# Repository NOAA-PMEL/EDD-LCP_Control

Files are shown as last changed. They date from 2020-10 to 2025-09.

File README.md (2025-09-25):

# Legal Disclaimers

## Software Disclaimer
*This repository is a software product and is not official communication 
of the National Oceanic and Atmospheric Administration (NOAA), or the 
United States Department of Commerce (DOC).  All NOAA GitHub project 
code is provided on an 'as is' basis and the user assumes responsibility 
for its use.  Any claims against the DOC or DOC bureaus stemming from 
the use of this GitHub project will be governed by all applicable Federal 
law.  Any reference to specific commercial products, processes, or services 
by service mark, trademark, manufacturer, or otherwise, does not constitute 
or imply their endorsement, recommendation, or favoring by the DOC. 
The DOC seal and logo, or the seal and logo of a DOC bureau, shall not 
be used in any manner to imply endorsement of any commercial product 
or activity by the DOC or the United States Government.*

## Hardware Disclaimer
*NOAA does not intend to patent this work worldwide. It may be used freely, but NOAA does not warrant its fitness for any use.*

*As a work of the United States Government, the associated schematics and software are in the public domain within the United States. Additionally, NOAA waives any potential copyright and related rights in the associated schematics and software worldwide through the Creative Commons Zero (CC0) 1.0 Universal Public Domain Declaration.*
# EDD-LCP_Control
Control PCB &amp; Firmware for Low Cost Profiler.

This repository is home to the system controller PCB design and firmware for the low-cost profiler project.

## State of this project
The LCP has been extensilivly tested and deployed in Puget Sound and the Bering Sea in Moored mode.  The mechanical design is complete, the electronics hardware needs a goround-up re-design for lower power consumption, decreased cost, and robustness.  The Firmware needs a ground up re-write for robustnuss and readability.

# Branch
Ver1.0 is the active branch and encompasses the most upto date version of the project 

# Low-Cost-Profiler
Low Cost Profiler for Oceanographic Monitoring

## Profiler System Diagram
```mermaid
graph LR;

    subgraph Low Cost Profiler

    MainController --- PistonController
    GPS --> MainController
    Pressure --> MainController
    Temperature --> MainController
    IMU --> MainController
    Accelerometer --> MainController
    subgraph Profiler Control
        MainController
        subgraph sensors
            Pressure
            Temperature
            GPS 
            IMU
            Accelerometer
        end

        IridiumSBD --- MainController
        subgraph Telemetry
        IridiumSBD
        end
    end

    subgraph Power Control ;
    Piston --> PistonController
    Encoder --> PistonController
    subgraph motion
    Encoder
    Piston
    end
    Batteries --> PistonController
    subgraph power
    Batteries
    end
    BatteryFuelGauge --> PistonController
    subgraph Sensor2
    BatteryFuelGauge     
    end
    end
    
    end
```

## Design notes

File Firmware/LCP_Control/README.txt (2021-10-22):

Name:
=====
 freertos_lowpower

Description:
============
 Example of the app running under FreeRTOS.

This example implements LED task within the FreeRTOS framework. It monitors
three On-board buttons, and toggles respective on-board LEDs in response.
To save power, this application is compiled without print
statements by default. To enable them, add the following project-level
macro definitions.

AM_DEBUG_PRINTF

If enabled, debug messages will be sent over ITM.

******************************************************************************

State of the world (project):

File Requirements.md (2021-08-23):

# LCP Control Requirements

## Introduction
This document captures the electrical and firmware requirements of the Low-Cost Profiler.

## Electrical Requirments

## Firmware Requirements
### Sensors
- [ ] Pressure sensor
- [ ] Temperature sensor
- [ ] GPS
- [ ] Accelerometer
  - [ ] Double tap recognition
  - [ ] Tilt 
  - [ ] Oscillation

### COMs
- [ ] UART 
- [ ] I2C
- [ ] SPI
- [ ] Iridium 
- [ ] Bluetooth

### Analog
- [ ] Bus voltage monitoring

### Low Power Mode
- [ ] Low Power Mode

### Application Level
  - [ ] Console
    - [ ] Set
      - [ ] See Config Parameters
    - [ ] Get 
      - [ ] See Config Parameters
    - [ ] Stream data
      - [ ] Debug
      - [ ] Warnings
      - [ ] Errors
      - [ ] All
  - [ ] Config
    - [ ] Bluetooth Config
    - [ ] Other?
  - [ ] Control Mode
    - [ ] Dive Mode
    - [ ] Park Mode
    - [ ] Dive 2 Mode
    - [ ] Profile Mode
    - [ ] Surface Mode
    - [ ] Transmit Mode
  - [ ] Deployment Mode
    - [ ] Storage Mode
    - [ ] Config Mode
    - [ ] Deploy Mode
    - [ ] Seek Mode
    - [ ] Profile Mode
    - [ ] Moored Mode
    - [ ] Pop-up Mode
  - [ ] Motion Control
    - [ ] State/Estimation
    - [ ] Current state
    - [ ] Piston Control
  - [ ] Data Acquisition
    - [ ] Depth Estimation
    - [ ] Chemistry
      - [ ] Temperature
      - [ ] CTD [Future] 
      - [ ] Chlor-A [Future]
      - [ ] PAR [Future]
    - [ ] Position/Tilt
      - [ ] GPS
      - [ ] Accleration
      - [ ] IMU
  - [ ] RTOS
    - [ ] Modes
    - [ ] Threads
    - [ ] Scheduling
    - [ ] Queues

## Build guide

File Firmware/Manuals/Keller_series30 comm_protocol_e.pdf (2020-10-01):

KELLER AG für Druckmesstechnik | Version 3.5 BV/SM 27. January 2017

# Description of the Communication protocol

for Series 30 and Series40 pressure transmitters from KELLER Class.Group = 5.20
Class.Group = 5.21

Version 3.5

Communication protocol Serie30 | Page 2/36

### 1 Introduction

This document describes the communications protocol for the Series 30 digital pressure transmitters from KELLER Druckmesstechnik. In addition to these transmitters, other devices such as data loggers or manometers are also offered. These products are distinguished by the designation CLASS. Within this device class, the individual device groups are differentiated by the designation GROUP. All Series 30 pressure transmitters bear the CLASS designation 5.

The software version number consists of following components:

short-designator: | Class | Group | Year | Week
| Device group | | SW-Version
Series 30 and 40 | 5 | 20 | SW-Version: release year | SW-Version: release week
Series 30 X2 | 5 | 21 | SW-Version: release year | SW-Version: release week

In this document, the software version is defined by Class.Group-Year.Week, e.g. 5.20-5.50.

The protocol itself is based on MODBUS, but incorporates optimised functions for the device, these functions are called Keller bus functions. However, minimum (only fct3) MODBUS RTU functionality is implemented for devices CLASS.GROUP = 5.20 with firmware 2.40 and newer. Full MODBUS support is provided from firmware 5.20-10.XX on and in 5.21-XX.XX.

See Appendix for an overview of the different versions.

### 2 Bit transfer layer (physical layer)

### 2.1 Introduction

The physical connection is provided by the RS485 serial interface. This guarantees good interference immunity and enables a flexible bus structure, i.e. several devices can be administrated as slaves by a single master. In order to minimise the scope of cabling, the RS485 is used in half-duplex mode. This means that 2 wires are required for communications and 2 wires for power in feed.

### 2.2 Characteristic

In order to operate several devices at one serial interface, they are simply all connected in parallel (RS485A, RS485B, GND and +Vcc). Before incorporating the devices into the bus, each device must be programmed with a different address.

It is possible to configure a network up to a length of 1300 metres with a maximum of 128 devices. Each riser cable may be up to 14 m in length. The employed cable should correspond to specification EIA RS485.

master

max. 1300m

max. 14m

dev. 1 | dev. 2 | dev. n

### 2.3 RS485 half-duplex details

To ensure best possible operation in an industrial environment Keller uses RS485 driver with tailored characteristics. To provide compatibility and get full advantage the bus driver of the master device has to support these specifications.

slew rate limited | In order to avoid oscillations and interference the signal slew rate is limited. This measure allows also usage of standard cables or non-standard topologies (e.g. level detectors or branch lines >> 14m). The more, termination is less critical and has not to be implemented compulsory at the line ends, a feature important for level detectors.
fail safe | Defined signal level – even in short or open circuit case. This is very important for half-duplex operation if all devices are in reception mode – here the line is open in case that no bias resistors are implemented at the master.
1/8 unit load | Input impedance is lower than defined by the RS485 standard, this allows connecting up to 128 devices to the bus.

Termination
Layout: between A and B at the beginning and the end of the transmission line

Value: the same as the line-impedance. Type.: 120Ohm.

In case of a fail-safe master driver (interface converter to the PC) and a noise-free environment the termination resistor are not mandatory. To reduce current peaks the resistor value can be chosen higher (1kOhm) or omitted (while transmitting the current needed for 2x120Ohm is about 50mA).

To ensure a stable communication at least one terminal resistor is necessary (mostly included in the master-RS485 driver)! One can do without a terminal resistor, if the environment is free of interference and the cable is held short (a few meters).

If the transmitter has additionally an analogue 4...20mA (two wire) output which will be used simultaneously with the serial communication, it could be useful to communicate without terminal resistor. Otherwise the analogue current signal will have heavy interferences. See application note: App. Note S30X-011 RS485 and current loop.pdf

The transmitters will never have a terminal resistor built in internally.

Bias-resistors
To keep up having always defined voltages one can switch pull-up respectively pull-down resistors to the transmitter:
From A to +5V and from B to GND. This is necessary when such RS485 drivers are in use which are not fail-save. This is not necessary for our products when the master is fail-safe.

Common Mode
The common-mode of the data circuit line is +12 / -7V down to GND. It is essential to keep up with this. Always connect the GND of the RS485 converter of the master with GND of the transmitter!

Definition of data circuit line assignments
signal | Designation of Keller and divers manufacturers… | Designation of the EIA Standard
inverted (-) | B | A
non-inverted (+) | A | B

Further information on RS485: http://www.maxim-ic.com/MaximProducts/Interface/rs-485.htm

### 3 Data-link layer

This section describes how data interchange is affected on this bus. The data and their check and control structures are grouped together to form messages. These constitute the smallest communication unit, i.e. only messages can be exchanged between the devices. As a half-duplex protocol is in use here, only one device can use the bus as a transmitter at any one time. All other devices are then in receive mode. The master takes the form of a PC or microcontroller, for example, and the devices are the slaves. Each message exchange takes place under the control of the master. The message contains the address for the receiving slave.

This results in the following 2 options for data interchange:

a) Broadcasting | This mode of communication enables the master to transmit a message to all slaves simultaneously. The master does not receive a reply, however, and is thus unable to check whether the message has been correctly received by every slave.
b) Data interchange | This mode of communication enables the master to communicate with a single slave. This normally involves the transmission of two messages: the master transmits a request and the slave responds to this request. Only the master is permitted to request a response. The request is received by every slave, but only the selected slave responds. The response must be received within a stipulated time, otherwise the master will assess the attempt as failed and must transmit the request again.

### 3.1 Transmission format for the serial interface

The data are transmitted serially via the bus. The following format applies:
- 1 start bit
- 8 data bits (the least significant bit first)
- 1 stop bit
- no parity (default)
- 9600 baud (default) or 115’200 Baud

This results in 10 bits (11 bits with active parity bit) per transmission byte.

### 3.2 Format of a message

### 3.2.1 Format of the message sent by the master

Note on the presentation of messages: Each box presents 1 data byte consisting of 8 bits, unless otherwise stated.

Each message sent by the master possesses the following format:

DevAddr | 0 | Function code
n byte parameters
(optional)

KELLER:CRC16_H
MODBUS:CRC16_L

KELLER:CRC16_L
MODBUS:CRC16_H
- DevAddr: Address of the device.
Address 0 is reserved for broadcasting.
Addresses 1 (default) ...249 can be used for bus mode.
Address 250 is transparent and reserved for non-bus mode. Every device can be contacted with this address. Addresses 251...255 are reserved for subsequent developments.
- Function code: Function number
A function is selected and executed by the device via the function number. The function number is encoded in 7 bits. Bit 7 is always 0. The functions are described further below.
- Parameters: The parameters required by the function (n = 0 .. 6, according to function)

- CRC16: 16-bit checksum
These two check bytes serve to verify the integrity of the received data. If an error is established, the entire message will be discarded. The principle employed for CRC16 calculation is described in the appendix. The CRC16 standard is applied here.

Note: The length of a message from the master is at least 4 bytes.

### 3.2.2 Format of the message sent by the slave

A message transmitted by the slave possesses the following format:

DevAddr | X | Function
| | code

n byte data
(optional)

KELLER:CRC16_H
MODBUS:CRC16_L

KELLER:CRC16_L
MODBUS:CRC16_H
- DevAddr: Address of the device. This address corresponds to the address of the responding device.
- Function code:
The function number is identical to the function number sent by the master. If the most significant bit is X = 0, this indicates that the function has been executed correctly. If bit X = 1, an exception error has occurred.
- Data: Any data requested via the function follow here.
- CRC16: See above.

Note: A message from the slave has a minimum length of 5 bytes, and a maximum length of 10 bytes (Class.Group-version = 5.20-XX.XX) or 100 bytes (Class.Group-version = 5.21-XX.XX).

### 3.3 Principle of message interchange

### 3.3.1 General rules

- An address may only be allocated to one device connected to the bus. If two devices on the bus have the same address, both will respond, leading to a conflict.
- Every data interchange is initiated by the master. This means that a device may only transmit data if requested to do so by the master.
- A message consists of several bytes. These bytes are transmitted without any interruption.
Maximal time between two bytes:
1.5ms @ 9600 baud (1.5 byte length)
0.20 ms @ 115200 baud (2.3 byte length)
If the time between two bytes exceed the specified time, the slave ignores the received data, because of wrong message length or CRC value. In that case the answer is omitted.
- The addressed device must respond within time T1, otherwise the message will be invalid.

Bit frame:

ST | D0 | D1 | D2 | D3 | D4 | D5 | D6 | D7 | SP | ST | D0 | … | D6 | D7 | SP
ST: start bit, | SP: stop bit. A parity bit (if active) is inserted before the SP, D0 .. D7: 8 data bits

Message frame:

Response times:
- T1: Time between receipt of inquiry and beginning of response.
min 1.2 ms @ 9600 baud to max. 100ms for all functions and devices.
min 1 ms @ 115200 baud to max. 100ms for all functions and devices.
firmware 5.20: | Most functions (except those with EEPROM access like information values):T1 min. 1.2… 3ms
firmware 5.21: | T1 : 1.3ms – 1.8ms for F30, F32, F48, F69,F73 and F74
T1 : 7.3ms – 7.6ms for F31, F33, F66 and F95
With Modbus communication the duration of T1 depends on the number of register to read or write, while write takes much more time than read. (Write: typ. 7.2ms per register)
- T2: Time to ready-to-receive state for the slave: min 0.5 ms @ 9600 baud
min 0.5 ms @ 115200 baud

### 3.3.2 Treatment of errors

2 types of errors may occur during the interchange of messages between master and slave: transmission errors and exception errors.

### 3.3.2.1 Transmission errors

These errors are primarily accountable to line faults. The message format is incorrect. The following problems are possible:
- A received message is too short. → e.g. too much of time gap in frame between the bytes.
- A message is longer than the internal transmission buffer permits.
- The word length cannot be interpreted correctly.
- The CRC16 checksum is incorrect.
In these cases the slave denies the request and will therefore not reply. This will lead to a timeout at the master. → the request has to be repeated again.
In response to a transmission error, all received data are ignored. The slave remains in receive mode while the master is required to initiate a new data interchange.

### 3.3.2.2 Exception errors

The message has been received correctly (no transmission error has occurred), but the transmitted function number and/or the parameters are invalid. The slave responds with an exception error, unless the message has been received in broadcasting mode.
The message transmitted as a response by the slave has the following format:
DevAddr | 1 | Function
code

Exception
code

KELLER:CRC16_H
MODBUS:CRC16_L

KELLER:CRC16_L
MODBUS:CRC16_H

5 types of exception errors are defined:
- | illegal non-implemented function | 1
- | illegal data address | 2
- | illegal data value | 3
- | Slave device failure | 4
- | initialisation (only KELLER bus) | 32

Exception error 32 occurs when the device is started up anew and initialisation has not been carried out. This happens every time the device is connected anew after a break in the power supply.

Master:
Request

Master:
Request

Slave:
Response
T1 | T2

### 4 MODBUS communication

### 4.1 MODBUS Communication Basics

Mode: | RTU Mode (ASCII is not supported)
Coding System: | 8–bit binary, hexadecimal 0–9, A–F
| Two hexadecimal characters (bytes) contained in each 8–bit field of the message
Bits per Byte: | 1 start bit
| 8 data bits, least significant bit sent first
| No parity (default) 1 parity bit: even or odd parity (programmable)
| 1 stop bit (default) 2 stop bit (programmable) only firmware 5.21-XX.XX
Error Check Field: | 2 Byte Cyclical Redundancy Check (CRC)
Baudrate: | programmable 9’600 (default) or 115’200

Frame Layout:
> 3.5 char (byte) start delimiter | 8 bit addr 8 bit fkt code n x 8bit data (max n = 252)

16 bit
CRC
LOW / HIGH

> 3.5 char (byte)
end delimiter

The entire message frame must be transmitted as a continuous stream of characters. If a silent interval of more than 1.5 character times occurs between two characters, the message frame is declared incomplete and should be discarded by the receiver.

Bus Addressing:
Unicast addresses: each slave has an address between 1 (default) and 247.
Broadcast addresses: address 0 is used for broadcast frames, the slave accepts the command but must not generate an answer. Special addresses: addresses 248 – 255 are reserved. The address 250 is used for non-bus (point-to-point) communication to address a slave with unspecified or unknown address (not MODBUS standard).

Function Code:
The 8-bit value function code describes the operation that is performed on the slave. Implemented MODBUS functions are described in the following chapter.

### 4.2 Using MODBUS with KELLER products

Both protocols are active. For MODBUS only a subset of the MODBUS functionality is implemented and the implemented MODBUS function codes are not used in the KELLER-protocol. Please note, that the responses are different for both protocols.

Furthermore note that for MODBUS communication NO initialization is required to be performed before any other command.

Attention: The Error Check Field byte alignment differs.
| Modbus | KELLER-Protocol
CRC-16 | L:H | H:L

### 4.3 Description of MODBUS functions

This section describes the MODBUS functions supported by Series 30 transmitters (device Class.Group = 5.20-XX.XX and 5.21-XX.XX)

Overview:
F3: | Read registers on MODBUS address space
F6: | Write single register on MODBUS address space
F8: | MODBUS Echo function
F16: | Write multiple registers on MODBUS address space

Versions overview
The main difference between firmware 5.20 and 5.21 is, that the buffer size in version 5.21 is larger (100 byte).
The table below gives you an overview which Firmware-version supports which MODBUS functions:
Version | F3 float values 0x0000..0x000A | F3 float values 0x0100..0x0106 | F3 int 16bit values 0x0010.. 0x0015 | F3 int 32bit values 0x0020.. 0x002A | F3 Information& Configuration | F6 | F8, F16 | Data buffer size
5.20-5.50 | Yes | No | Yes | No | No | No | No | 10 byte
5.20-10.40 | Yes | Yes | No | No | Yes | No | Yes | 13 byte
5.20-12.28 | Yes | Yes | Yes | Yes | Yes | Yes | Yes | 13 byte
5.21-13.10 (and later) | Yes | Yes | Yes | Yes | Yes | Yes | Yes | 100 byte

Note: compatible for all versions to read process values (CH0..TOB2): F3 float, reg 0x0000..0x000A

### 4.4 Modbus Communication Examples

Read | address | request | response | received value
P1 | 1 | 1 3 0 2 0 2 101 203 | 1 3 4 63 117 240 123 227 222 | 0.960701 bar
P2 | 1 | 1 3 0 4 0 2 133 202 | 1 3 4 63 118 6 224 21 213 | 0.961042 bar
TOB1 | 1 | 1 3 0 8 0 2 69 201 | 1 3 4 65 181 192 121 110 11 | 22.719 °C
P1, TOB1 | 1 | 1 3 1 0 0 4 69 245 | 1 3 8 63 117 227 210 65 182 28 32 160 119 | 0.960508 bar 22.7637 °C

### 4.5 Function 3: MODBUS Register Read

Read a number of subsequent registers in the MODBUS address space starting with StAdd. Note, that the data returned has to be interpreted according the definitions in “4.9 MODBUS Register Map”.
- Function is implemented in devices Class.Group-version = 5.20-2.40 and later and 5.21-XX.XX.
- The maximal number of registers read in one cycle is limited to:
up to 4 registers for versions Class.Group-version = 5.20-10.40 and later
up to 80 registers for versions Class.Group-version = 5.21-XX.XX
up to 2 registers for earlier versions than Class.Group-version = 5.20-10.40
- Byte-count of the answer will be an even number (1 register = 2 bytes)
- Double sized process values (CH0, P1, P2, T, TOB1 and TOB2) must be read in one request.
- Returns NaN (float) or ovl (integer) in case of a inactive channel or a error in the channel

Request:
DevAddr | 0x03 | StAdd H | StAdd L | # Reg H | # Reg L | CRC16_L | CRC16_H
Response:
DevAddr | 0x03 | # Bytes | Data H | Data L | … | Data L | CRC16_L | CRC16_H
Error:
DevAddr | 0x83 | Error | CRC16_L | CRC16_H
Error codes:

### 2 Illegal data address:

- Wrong starting-address or wrong number of registers
- Start-address not defined, register exceeding defined range return 0x0000

### 3 Illegal data value:

- Quantity of requested registers out of bound

- Must be <= 4 for devices Class.Group-version = 5.20-10.XX and later
- Must be <= 80 for devices Class.Group-version = 5.21-XX.XX
- Must be <= 2 for devices Class.Group-version = 5.20-2.50

### 4.6 Function 6: MODBUS Single Register Write

This function has the same functionality as F16, but writes only 1 register.
- Function is implemented in devices Class.Group-version = 5.20-12.XX and later and 5.21-XX.XX
- A register contains 2 bytes (16 bit).
- Use this function for single configuration steps, because the returned error is easily distinguishable from other register writes.
- Note that single register operations are not allowed in the address ranges 0x03XX and 0xFFXX.

Request:

DevAddr | 0x06 | StAdd H | StAdd L | Data H | Data L | CRC16_L | CRC16_H

Response:

DevAddr | 0x06 | StAdd H | StAdd L | Data H | Data L | CRC16_L | CRC16_H

Error:

DevAddr | 0x86 | Error | CRC16_L | CRC16_H

Error codes:

### 2 Illegal data address

- address not accessible by function 6
- Start-address not defined (for writing)

### 3 Illegal data value

- frame length incorrect

### 4 Slave Device Failure

- Attempted to write into a protected register
- The data written is outside the defined data range

### 4.7 Function 8: MODBUS Echo Test

This function may be used to perform a quick line check. It just returns the data received.
- Function is implemented in devices Class.Group-version = 5.20-10.XX and later and 5.21-XX.XX
- Data may be any 2 byte value

Request:

DevAddr | 0x08 | 0x00 | 0x00 | Data H | Data L | CRC16_L | CRC16_H

Response:

DevAddr | 0x08 | 0x00 | 0x00 | Data H | Data L | CRC16_L | CRC16_H

Error:

DevAddr | 0x88 | Error | CRC16_L | CRC16_H

Error codes:

### 1 Illegal subfunction code:

- The subfunction code is not supported (it is not (0x00, 0x00)). Class.Group-version = 5.21-XX.XX only

### 3 Illegal data value:

- The data following the function code was not the fixed data (0x00, 0x00). Class.Group-version = 5.20-10.XX and later

### 4.8 Function 16: MODBUS Register WRITE

Write a number of subsequent registers on the MODBUS address space starting with StAdd.
- Function is implemented in devices Class.Group-version = 5.20-10.XX and later and 5.21-XX.XX
- A register contains 2 bytes (16 bit).
- The number of registers written in one cycle is limited to 2 (0x02) for Class.Group-version = 5.20-10.XX
- The number of registers written in one cycle is limited to 40 (0x28) for Class.Group-version = 5.21-XX.XX
- Byte-count of the answer will be an even number (1 register = 2 bytes).
- Addresses above 0xFF00 are virtual command registers that simply execute a task on the slave. Please refer to chapter “4.9 MODBUS Register Map” for more information.
- Writing float values (0x03XX and 0xFFXX) always requires 2 data registers.
- #Reg in the response declares the number of actually written registers (in case an error occurs, this amount is not the same as in the request)

Request:
DevAddr | 0x10 | StAdd H | StAdd L | # Reg H | # Reg L | # Bytes | Data H | Data L
… | Data H | Data L | CRC16 L | CRC16 H

Response:
DevAddr | 0x10 | StAdd H | StAdd L | # Reg H | # Reg L | CRC16_L | CRC16_H

Error:

DevAddr | 0x90 | Error | CRC16_L | CRC16_H

Error codes:

### 2 Illegal data address:

- Undefined starting-address or wrong number of registers
- Start-address not defined (for writing)

### 3 Illegal data value:

- The amount of data is out of bound
- Byte-Count is not twice the # Reg.

### 4 Slave Device Failure:

- Attempted to write into a protected register
- The data written is outside the defined data range

### 4.9 MODBUS Register Map

Process Value Read Range (0x000x) 32bit floating point:
- compatible with Class.Group-version = 5.20-5.50 and later and 5.21-XX.XX
- A Channel must be read in one cycle. Odd start address (StAdd) returns exception2
- format is float according to chapter “6.2 Floating-point format IEEE754”,
5.20-5.50: 2Registers. Errors: Inactive Channel returns exception2, ovl or uvl returns exception3
5.20-10.40 and later and 5.21-XX.XX: 2 or 4 Registers. Errors: Inactive Channel returns NaN, over-/underflow is represented by +/-infinity
- corresponding functionality to Keller Bus functions F73
MODBUS StAdd (0xHILO) | Channel | Read/ Write | Unit | Description
0x0000 | CH0 | R | --- | Calculated value (customer specific format) HWord
Calculated value (customer specific format) LWord
0x0002 | P1 | R | bar | Pressure of sensor1 HWord
| | | | Pressure of sensor1 LWord
0x0004 | P2 | R | bar | Pressure of sensor2 HWord
| | | | Pressure of sensor2 LWord
0x0006 | T | R | °C | Temperature HWord
| | | | Temperature LWord
0x0008 | TOB1 | R | °C | Temperature of sensor1 HWord
| | | | Temperature of sensor1 LWord
0x000A | TOB2 | R | °C | Temperature of sensor2 HWord
| | | | Temperature of sensor2 LWord

Process Value Read Range (0x001x) 16bit integer:
- compatible with Class.Group-version = 5.20-5.50 and later and 5.21-XX.XX, but not 5.20-10.40
- format is 2 byte signed integer
- All Values are multiplied by 100. Numeric range: +/- 32700, max. pressure +/- 327bar.
Use 32bit Register for higher resolution and range.
- Amount of Registers: 5.20-5.50: 1Reg, version 5.20-12.28 and later and 5.21-XX.XX: 1 .. 4Reg.

Error-Handling:
Channel not active or error (NaN): value = 32767 (version 5.50: exception2) Overflow or value > 327.0 : value = 32767 (version 5.50:exception 3) Underflow or value < -327.0: value = -32768 (version 5.50: exception3)
MODBUS StAdd (0xHILO) | Channel | Read/ Write | Unit | Description
0x0010 | CH0 | R | 1/100 -- | Calculated value (customer specific format)
0x0011 | P1 | R | 1/100 bar | Pressure of sensor1
0x0012 | P2 | R | 1/100 bar | Pressure of sensor2
0x0013 | T | R | 1/100 °C | Temperature
0x0014 | TOB1 | R | 1/100 °C | Temperature of sensor1
0x0015 | TOB2 | R | 1/100 °C | Temperature of sensor2

Process Value Read Range (0x002x) 32bit integer:
- compatible with Class.Group-version = 5.20-12.28 and later and 5.21-XX.XX
- A Channel must be read in one cycle. Odd start address (StAdd) returns exception2
- format is 4 byte signed integer
- Overflow returns “2147483647”, an underflow “-2147483648”
- Error in a Channel or Channel not active returns “2147483647”
- corresponding functionality to Keller Bus functions F74
MODBUS StAdd (0xHILO) | Channel | Read/ Write | Unit | Description
0x0020 | CH0 | R | 10-5 --- | Calculated value (customer specific format) HWord
Calculated value (customer specific format) LWord
0x0022 | P1 | R | Pa (10⁻⁵bar) | Pressure of sensor1 HWord
0x0024 | P2 | R | Pa (10⁻⁵bar) | Pressure of sensor2 HWord

Pressure of sensor1 LWord

Pressure of sensor2 LWord
0x0026 | T | R | 1/100 °C | Temperature HWord
| | | | Temperature LWord
0x0028 | TOB1 | R | 1/100 °C | Temperature of sensor1 HWord
| | | | Temperature of sensor1 LWord
0x002A | TOB2 | R | 1/100 °C | Temperature of sensor2 HWord
| | | | Temperature of sensor2 LWord
Remark: Pressure unit is Pascal (10⁻⁵ bar) instead of bar

Process Value Read Range (0x0100) 32bit floating point:
- compatible with Class.Group-version = 5.20-10.XX and later and 5.21-XX.XX
- Same as 0x0000 .. 0x000B but different mapping for accessing data in one cycle (e.g. P1 and TOB1)
MODBUS StAdd (0xHILO) | Channel | Read/ Write | Unit | Description
0x0100 | P1 | R | bar | Pressure of sensor1 [bar] HWord
Pressure of sensor1 [bar] LWord
0x0102 | TOB1 | R | °C | Temperature of sensor1 [°C HWord
| | | | Temperature of sensor1 [°C] LWord
0x0104 | P2 | R | bar | Pressure of sensor2 [bar] HWord
| | | | Pressure of sensor2 [bar] LWord
0x0106 | TOB2 | R | °C | Temperature of sensor2 [°C] HWord
| | | | Temperature of sensor2 [°C] LWord
0x0108 | P1 | R | bar | Pressure of sensor1 [bar] HWord version 5.21-XX.XX only
0x010A | T | R | °C | Temperature [°C Hword version 5.21-XX.XX only

Pressure of sensor1 [bar] LWord version 5.21-XX.XX only

Temperature [°C] Lword version 5.21-XX.XX only
0x010C
ConTc | R | mS/cm

Conductivity Temperature Compensated [mS/cm] HWord version 5.21-XX.XX only
Conductivity Temperature Compensated [mS/cm] LWord version 5.21-XX.XX only

Device Configuration Range (0x02xx):
- compatible with Class.Group-version = 5.20-10.XX and later and 5.21-XX.XX
- all registers contain 16 bit [15..8][7..0] (1 register), high byte = 0x00 if not specified differently
- corresponding functionality to Keller Bus functions F32, F33, F66 and F69
MODBUS StAdd (0xHILO) | Read/ Write | Reg. Name | DESCRIPTION
0x0200 | R/W | UART | UART settings: Bit 0 .. 3: Baud rate Baud rate Value = 0: 9’600baud Baud rate Value = 1: 115’200baud Bit 4: Parity selection. 0: no Parity, 1: Parity enable Bit 5: Parity mode. 0: odd parity, 1: even parity Bit 6: Stop bit. 0: 1 stop bit, 1: 2 stop bit version 5.21-XX.XX only
0x0201 | R | FILTER_ORG | Factory setting for filter value. version 5.20-XX.XX only
0x0202 | R | S/N-H | Serial Number High Bytes (16bit)
0x0203 | R | S/N-L | Serial Number Low Bytes (16Bit)
0x0204 | R | CFG_P | Active pressure channels (high priority): Bit 1: P1, Bit 2: P2
0x0205 | R | CFG_T | Active temperature channels (low priority): Bit 3: T (Temperature sensor) Bit 4: TOB1 (Temperature of pressure sensor P1) Bit 5: TOB2 (Temperature of pressure sensor P2) Bit 7 Con (Conductivity sensor) version 5.21-XX.XX only
0x0206 | R/W | CFG_CH0 | version 5.20-XX.XX only CH0 (Calculated channel): Byte value (decimal): Device has to be restarted after change. 0: inactive 1: Difference P1 – P2 2: Difference P2 – P1 3: Square root calculation sqrt(P1) 4: Square root calculation sqrt(P2) 5: Square root calculation sqrt(P1 – P2) 6: Square root calculation sqrt(P2 – P1) 11: Absolute value = |P1| 12: Absolute value = |P1 – P2| 13: Line pressure compensated differential pressure (only at factory, add. parameters) 14: straight line curve fitting of P1 (only if P2 is not active, 5.20-12.24 and earlier)
0x0207 | R/W | CNT_T | Temperature measurement interval in seconds. version 5.20-XX.XX only
0x0208 | R/W | CNT_TCOMP LP_FILT | Value of Bit 3 ... 0 (LowNibble): CNT_TCOMP version 5.20-XX.XX only After CNT_T * CNT_TCOMP seconds a temperature compensation will be performed. Value of Bit 7 ... 4 (HighNibble): Low pass filter for P1 and P2. LowpassFilter = [B7 ..B4] The formula for the low pass filter is given as: where: Pn+1: new filtered value, Pn: actual measured value, Pn-1: old filtered value
0x0209 | R | P-Mode | version 5.20-12.28 and later and 5.21-XX.XX: Type of sensor and calibration Bit 3 ... 0 (LowNibble) P1:0: PR (relative), 1: PA (absolute), 2: PAA (absolute). Bit 7 ... 4 (HighNibble) P2:0: PR (relative), 1: PA (absolute), 2: PAA (absolute). Earlier version: Not used (return 0x0000)
0x020A | R/W | FILT_CTRL | Filter setting for one conversion: Bit 0: Adaptive filter for P1 and P2 (on / off) Bit 1: Low pass filter for T, TOB1 and TOB2 (on / off) Bit 2 .. Bit 4: Over sampling ration OSR = 2^(8+Bit 2 ... 4) version 5.20-XX.XX only Bit 5 .. 6: Amount of samples per averaging: 0 ..3 = 1, 2, 4 or 8 values. version 5.20-XX.XX only Factory settings see FILTER_ORG. version 5.20-XX.XX only
0x020B | R | DAC_CTRL | version 5.20-XX.XX only Analogue output: Bit 0: Milli Amperes output (4 .. 20mA) Bit 1: Voltage output Bit 4 = 1: P1 is linked to the analogue output Bit 4 = 0: CH0 is linked to the analogue output
0x020C | R | STATUS | Status, the same as the STAT byte from F73.

0x020D | R/W | DEV_ADDR | Device Address
0x020E | R | Class:Group | Firmware-version, 16Bit (only version 5.20-12.28 and later and 5.21-XX.XX)
0x020F | R | Year:Week | Firmware-version, 16Bit (only version 5.20-12.28 and later and 5.21-XX.XX)
0x0211 | R/W | ConOn | version 5.21-XX.XX only 0x01: Conductivity powered 0x00: Conductivity unpowered
0x0212 | R | STATUS | Not used
0x0213 | R/W | ConRange | version 5.21-XX.XX only 0x01:Conductivity Range 1: 0…200uS (0.2mS) 0x02: Conductivity Range 2: 0…2’000uS (2mS) 0x03: Conductivity Range 3: 0…20’000uS (20mS) 0x04: Conductivity Range 4: 0…200’000uS (200mS)
0x0214 | R/W | ConTempCompCoeff | Conductivity Temperature Compensation Method after DIN/EN 27888 version 5.21-XX.XX only 0x01: Linear Temperature Compensation @ 25°C 0x02: Linear Temperature Compensation @ 20°C 0x03: Non-linear Temperature Compensation (Table) @ 25°C
0x223 | R/W | SPS | Samples per Second: version 5.21-XX.XX only 5: 120 SpS 6: 240 SpS 7: 480 SpS
0x0250 – 0x0257 | R | ASCII Serial Nb | 16 byte serial number in ASCII (option) version 5.21-XX.XX only

Device Coefficient Range (0x03xx):
- compatible with Class.Group-version = 5.20-10.XX and later and 5.21-XX.XX
- address is calculated by (0x0300 + 2*{Coeff-No.}). {Coeff-No.} is defined in Function 30.
- read only an even number of registers
- format is float according to chapter “6.2 Floating-point format IEEE754”
- Writing only allowed with F16 (write cycle with 2 registers)
- corresponding functionality to Keller Bus functions F30 and F31
MODBUS StAdd (0xHILO) | Read/ Write | Coeff-No. | Unit | DESCRIPTION
0x036A | R/W | 53 | bar | Threshold value of the root function ( must be > 0 if sqrt function is used ) version 5.20-XX.XX only
0x0380 | R/W | 64 | bar | Offset of pressure sensor P1, default = 0.0
0x0382 | R/W | 65 | | Gain factor of pressure sensor P1, default = 1.0
0x0384 | R/W | 66 | bar | Offset of pressure sensor P2, default = 0.0
0x0386 | R/W | 67 | | Gain factor of pressure sensor P2, default = 1.0
0x0388 | R/W | 68 | | Offset of analogue output version5.20-XX.XX only
0x038A | R/W | 69 | | Gain factor of analogue output version5.20-XX.XX only
0x038C | R/W | 70 | | Offset of CH0, default = 0.0
0x038E | R/W | 71 | | Gain factor of CH0, default = 1.0
0x0390 | R/W | 72 | °C | Offset of temperature T version 5.21-XX.XX only
0x0394 | R/W | 74 | °C | Offset of temperature TOB1 version 5.21-XX.XX only
0x0398 | R/W | 76 | °C | Offset of temperature TOB2 version 5.21-XX.XX only
0x03A0 | R | 80 | bar | Minimum pressure of sensor P1
0x03A2 | R | 81 | bar | Maximum pressure of sensor P1
0x03A4 | R | 82 | bar | Minimum pressure of sensor P2
0x03A6 | R | 83 | bar | Maximum pressure of sensor P2
0x03A8 | R | 84 | °C | Minimum temperature of temperature sensor
0x03AA | R | 85 | °C | Maximum temperature of temperature sensor
0x03AC | R | 86 | °C | Minimum temperature of sensor P1
0x03AE | R | 87 | °C | Maximum temperature of sensor P1
0x03B0 | R | 88 | °C | Minimum temperature of sensor P2
0x03B2 | R | 89 | °C | Maximum temperature of sensor P2
0x03B4 | R | 90 | | Minimum value of channel CH0
0x03B6 | R | 91 | | Maximum value of channel CH0
0x03B8 | R | 92 | bar | Pressure for minimum analogue signal * version 5.20-XX.XX only
0x03BA | R | 93 | bar | Pressure for maximum analogue signal * version 5.20-XX.XX only
0x03B8 | R/W | 92 | bar | Pressure for minimum frequency signal version 5.21-XX.XX only
0x03BA | R/W | 93 | bar | Pressure for maximum frequency signal version 5.21-XX.XX only
0x03BC | R | 94 | mA, V | Minimum analogue signal*,** version5.20-XX.XX only
0x03BE | R | 95 | mA, V | Maximum analogue signal*,** version5.20-XX.XX only

0x03E0 | R/W | 121 | float | Gain Conductivity Range 1 version 5.21-XX.XX only
0x03E2 | R/W | 122 | float | Gain Conductivity Range 2 version 5.21-XX.XX only
0x03E4 | R/W | 123 | float | Gain Conductivity Range 3 version 5.21-XX.XX only
0x03E6 | R/W | 124 | float | Gain Conductivity Range 4 version 5.21-XX.XX only
0x03E8 | | | | Not used
0x03EA | R/W | 126 | float | Conductivity Temperature Coefficient (default 0.022-> water) version 5.21-XX.XX only
0x03EC | R/W | 127 | float | Conductivity Cell Constant (default 1.00) version 5.21-XX.XX only
0xFFD0 | R | - | U32 | Hardware Id
* Required for scaling the analogue output (see below)
**The information for No. 94 and No. 95 may be in mA or V, according to whether the device possesses a voltage output or a current output (see DAC_CTRL).

### 4.10 Device Operation Command List

- compatible with Class.Group-version = 5.20-10.XX and later and 5.21-XX.XX
- Writing only allowed with F16 (write cycle with 2 registers)
- Only one command per request
- This address range is NOT readable
- corresponding functionality to Keller Bus function F95
- Some bytes of the message are fixed, see following frame layout:
Request:
DevAddr | 0x10 | StAdd H | StAdd L | 0x00 | 0x02 | 0x04 | B3 | B2
B1 | B0 | CRC16 L | CRC16 H

Response:

DevAddr | 0x10 | StAdd H | StAdd L | 0x00 | 0x02 | CRC16_L | CRC16_H
MODBUS StAdd (0xHILO) | Read/ Write | Reg. Name | DESCRIPTION
0xFF00 | W | Set Zero P1 | The zero point value from P1 (Coeff-No. 64) is calculated, that the current measured value equals the floating point number specified.
0xFF02 | W | Reset Zero P1 | Zero Point Value from P1 is set to default (Coeff-No. 64 = 0.0)
0xFF04 | W | Set Zero P2 | The zero point value from P2 (Coeff-No. 66) is calculated, that the current measured value equals the floating point number specified.
0xFF06 | W | Reset Zero P2 | Zero Point Value from P2 is set to default (Coeff-No. 66 = 0.0)

0xFF08

0xFF0A
0xFF0C | W | Set Zero CH0 | The zero point value from CH0 (Coeff-No. 70) is calculated, that the current measured value equals the floating point number specified.
0xFF0E | W | Reset Zero CH0 | Zero Point Value from CH0 is set to default (Coeff-No. 70 = 0.0)
0xFF10 | W | Set Zero T | The zero point value from T is calculated, that the current measured value equals the floating point number specified. version 5.21-XX.XX only
0xFF12 | W | Reset Zero T | Zero Point Value from T is set to default (Coeff-No. 72 = 0.0) version 5.21-XX.XX only
0xFF14 | W | Set Zero TOB1 | The zero point value from TOB1 is calculated, that the current measured value equals the floating point number specified. version 5.21-XX.XX only
0xFF16 | W | Reset Zero TOB1 | Zero Point Value from TOB1 is set to default (Coeff-No. 74 = 0.0) version 5.21-XX.XX only
0xFF18 | W | Set Zero TOB2 | The zero point value from TOB2 is calculated, that the current measured value equals the floating point number specified. version 5.21-XX.XX only
0xFF1A | W | Reset Zero TOB2 | Zero Point Value from TOB2 is set to default (Coeff-No. 76 = 0.0) version 5.21-XX.XX only

### 5 Description of Keller bus functions

This section describes the functions of the bus protocol for Series 30 transmitters (device Class.Group 5.20-XX.XX and 5.21-XX.XX) using the Keller bus functions (not MODBUS).
Note that all numbers are shown as decimal (not as hex, contradictory to what was described in the MODBUS-chapters)!

Overview:
F30: | Read out calibration (scaling) and information floating-point values
F31: | Write calibration floating-point values
F32: | Read out configurations
F33: | Write configurations
F48: | Initialise devices, whereby the device ID is returned
F66: | Write bus address
F69: | Read out serial number
F73: | Read out current pressure and temperature values in floating-point format
F74: | Read out current pressure and temperature values in integer format
F95: | Zeroing functions

### 5.1 Example: read pressure value with exception handling

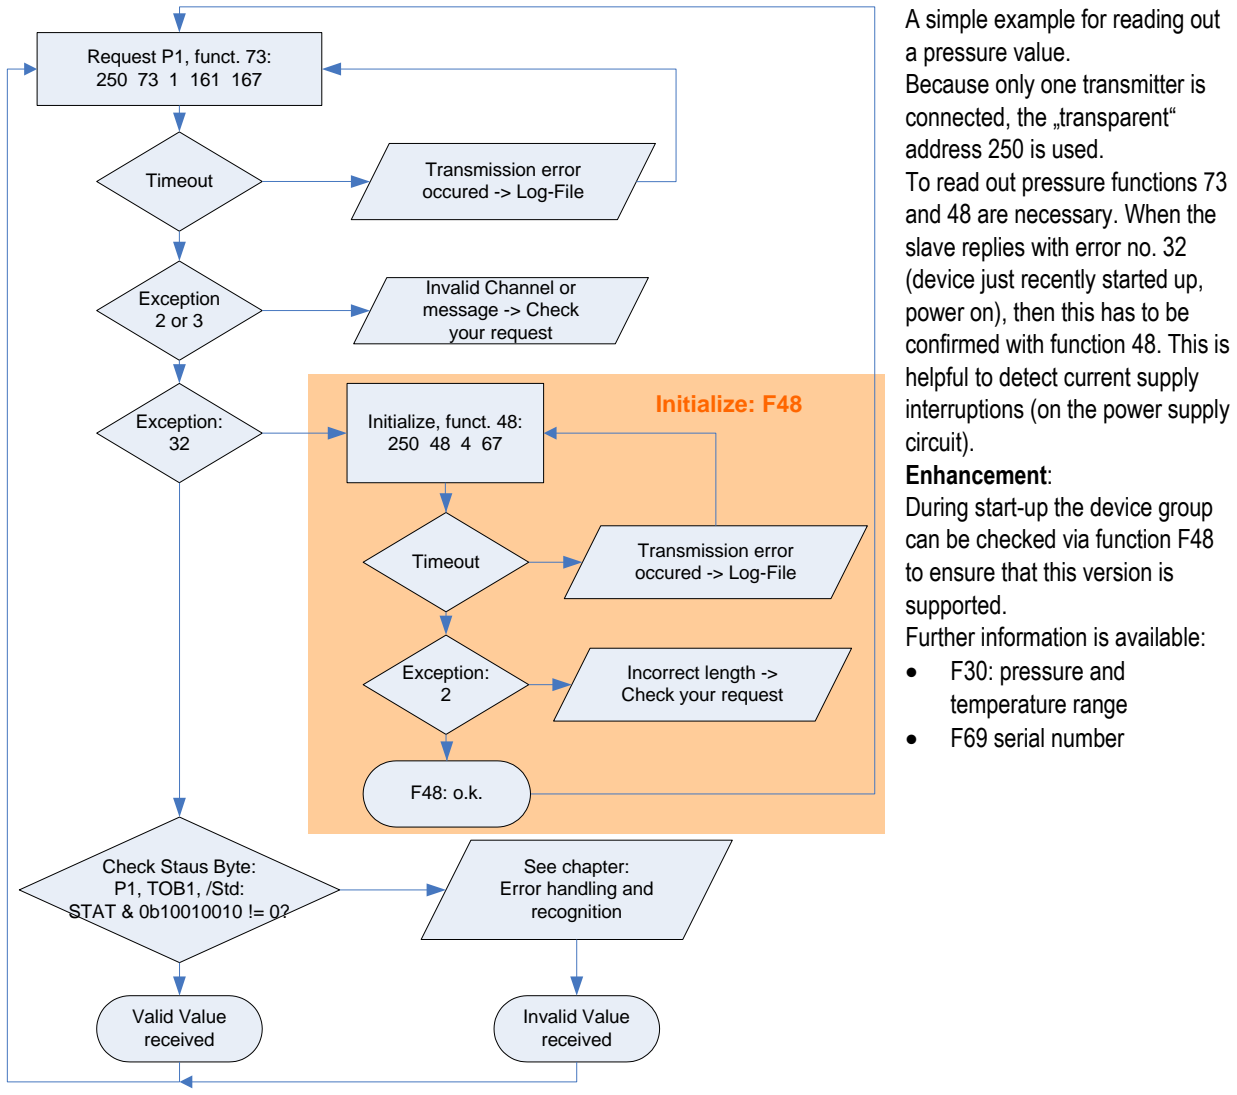
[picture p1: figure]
Exception: 32; Request P1, funct. 73: 250 73 1 161 167; Timeout; Initialize, funct. 48: 250 48 4 67; Exception 2 or 3; Check Staus Byte: P1, TOB1, /Std: STAT & 0b10010010 != 0?; Transmission error occured -> Log-File; Invalid Channel or message -> Check your request; Exception: 2; Incorrect length -> Check your request; See chapter: Error handling and recognition; Valid Value received; Invalid Value received; Initialize: F48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

Some examples:
| address | request | response | received value
Read P1 | 250 | 250 73 1 161 167 | 250 73 63 109 186 172 0 26 27 | 0.9286296 bar
| 1 | 1 73 1 80 214 | 1 73 63 109 177 83 0 231 97 | 0.9284870 bar
Read P2 | 1 | 1 73 2 81 150 | 1 73 63 109 178 242 0 119 232 | 0.9285117 bar
Read TOB1 | 250 | 250 73 4 162 103 | 250 73 65 201 184 0 0 224 204 | 25.21484 °C
| 1 | 1 73 4 83 22 | 1 73 65 202 81 128 0 95 54 | 25.28979 °C
Initialize | 1 | 1 48 52 0 1 48 52 0 | 1 48 5 20 1 48 5 21 | FW=5.20-5.50, Buffer=10, device already initialized

### 5.2 Function 30: Read coefficient

Request:

DevAddr | 30 | Nr. | CRC16_H | CRC16_L

Response:

DevAddr | 30 | B3 | B2 | B1 | B0 | CRC16_H | CRC16_L

Exception errors:

### 2 if no. > 111 3 if message length incorrect 32 if device is not yet initialised

Note:
Every coefficient can be read in IEEE754 format (floating-point format 4-byte B0 .. B3) via this function. → Information on IEEE754: see appendix.

### 5.2.1 Calibration values

No. | Read / Write | Description of coefficient | Unit
53 | R/W | Threshold value of the roof function, (must be >0 if sqrt is used) version5.20-XX.XX only | bar
64 | R/W | Offset of pressure sensor P1, default 0.0 | bar
65 | R/W | Gain factor of pressure sensor P1, default 1.0
66 | R/W | Offset of pressure sensor P2, default 0.0 | bar
67 | R/W | Gain factor of pressure sensor P2, default 1.0
68 | R/W | Offset of analogue output
69 | R/W | Gain factor of analogue output
70 | R/W | Offset of CH0, default 0.0
71 | R/W | Gain factor of CH0, default 1.0
72 | R/W | Offset of temperature sensor T version 5.21-XX.XX only | °C
74 | R/W | Offset of temperature sensor TOB1 version 5.21-XX.XX only | °C
76 | R/W | Offset of temperature sensor TOB2 version 5.21-XX.XX only | °C
72 | R/W | Upper threshold value for switching output 1** version 5.20-XX.XX only
73 | R/W | Lower threshold for switching output 1** version 5.20-XX.XX only
78 | R/W | Upper threshold value for switching output 2** version 5.20-XX.XX only
79 | R/W | Lower threshold for switching output 2** version 5.20-XX.XX only
121 | R/W | Gain Conductivity Range 1 version 5.21-XX.XX only
122 | R/W | Gain Conductivity Range 2 version 5.21-XX.XX only
123 | R/W | Gain Conductivity Range 3 version 5.21-XX.XX only
124 | R/W | Gain Conductivity Range 4 version 5.21-XX.XX only
126 | R/W | Conductivity Temperature Coefficient (default 0.022-> water) version 5.21-XX.XX only
127 | R/W | Conductivity Cell Constant (default 1.00) version 5.21-XX.XX only
100… 111 | R/W | free coefficients for customer use
** no longer supported for devices 5.20-10.XX and newer.
The calibration values can be read and written.

### 5.2.2 Information values

No. | Read / Write | Description of the coefficient | Unit
80 | R | Minimum pressure of sensor P1 | bar
81 | R | Maximum pressure of sensor P1 | bar
82 | R | Minimum pressure of sensor P2 | bar
83 | R | Maximum pressure of sensor P2 | bar
84 | R | Minimum temperature of temperature sensor | °C
85 | R | Maximum temperature of temperature sensor | °C
86 | R | Minimum temperature of sensor P1 | °C
87 | R | Maximum temperature of sensor P1 | °C
88 | R | Minimum temperature of sensor P2 | °C
89 | R | Maximum temperature of sensor P2 | °C
90 | R | Minimum value of channel CH0
91 | R | Maximum value of channel CH0
92 | R | Pressure for minimum analogue signal * version 5.20-XX.XX only | bar
93 | R | Pressure for maximum analogue signal * version 5.20-XX.XX only | bar
94 | R | Minimum analogue signal* version 5.20-XX.XX only | mA , V
95 | R | Maximum analogue signal* version 5.20-XX.XX only | mA , V
99 | R | Calibration date: B0:day B1:month B2:B3:year
120 | R | Conductivity hardware version and firmware version (C.G/Y.W) | -
* Required for scaling the analogue output (see below)

The information values are readable only.
The information for No. 94 and 95 may be in mA or V, according to whether the device possesses a voltage output or a current output (see DAC_CTRL function 33).

### 5.2.3 Scaling of channels CH0, P1 and P2

CH0, P1 and P2 are linearly scalable with zero point and gain factor: Value = gain factor * value + offset Standard values: Offset = 0.0, gain factor = 1.0
T, TOB1 and TOB2 are only scalable with zero point. Standard value: Offset = 0.0
It is also possible to influence the offset values via function 95 (see function 95).
The gain factor should be used for calibration purposes only, and not to alter pressure units. The latter operation should always be carried out by the master! In order to represent other pressure units via the analogue output, the unit conversion must be taken into account when scaling the analogue output.

### 5.2.4 Scaling the analogue output

The analogue output on the Series 30 pressure transmitters can be programmed via the interface. As the two routes sensor-signal → digital transformation and digital value → analogue signal are calibrated independently at the factory, the analogue output can be set to different pressures or pressure units without requiring recalibration. For this purpose, KELLER offers the free CCS30 software, which provides a convenient means of carrying out this scaling with a PC.

To programme the scaling of the analogue output yourself, proceed as follows:

Function 32 enables you to ascertain whether the device possesses an analogue output. The coefficients required for calculation can be read out using function 30. A new scaling can be programmed using function 31.

Read-out of pressure range for the analogue output:
The following coefficients (K[No.]) must be read out using function 30 in order to calculate the lower and upper limit of the analogue output:

A = (K[92] – K[68]) / K[69]
B = (K[93] – K[68]) / K[69]

Setting a new pressure range for the analogue output:
K[68] and K[69] must be calculated and written into the device using function 31:

K[68] = K[92] - ((K[93] – K[92]) / (B – A)) * A
K[69] = (K[93] – K[92]) / (B – A)

Whereby:
K[x]: Coefficient with the corresponding number [x] → see function 30
A: | Pressure in bar at which the signal K[94] is to be output
B: | Pressure in bar at which the signal K[95] is to be output
Other pressure units are to be converted into bar.

### 5.3 Function 31: Write coefficient

Request:

DevAddr | 31 | Nr. | B3 | B2 | B1 | B0 | CRC16_H | CRC16_L

Response:

DevAddr | 31 | 0 | CRC16_H | CRC16_L

Exception errors:

### 2 If write access is not allowed 3 If message length is incorrect 32 If device has not yet been initialised

Note:
Information on scaling of the channels: See functions 73 and 95. Information on which channels are active: See function 32 CFG_P, CFG_T and CFG_CH0.

### 5.4 Function 32: Read configuration

Request:

DevAddr | 32 | Nr. | CRC16_H | CRC16_L

Response:

DevAddr | 32 | Dates | CRC16_H | CRC16_L

Exception errors:

### 2 If no. is not available 3 If message length is incorrect 32 If device has not yet been initialised

Remark:
See description function 33

### 5.5 Function 33: Write configuration

Request:

DevAddr | 33 | Nr. | Dates | CRC16_H | CRC16_L

Response:

DevAddr | 33 | 0 | CRC16_H | CRC16_L

Exception errors:

### 2 If write access is not allowed 3 If message length is incorrect 32 If device has not yet been initialised

Remark:
With functions 32 and 33 one can read and write some configuration of the device. This functions provide a single byte access and replace function 100 / 101 for the devices with firmware Class.Group -Year.Week = 5.20-5.50 und earlier.

Description:
Nr. | Name | Description | Read | Write
0 | CFG_P | Active pressure channels (high priority): Bit 1: P1 Bit 2: P2 |
1 | CFG_T | Active Temperature channels (low priority): Bit 3: T (Temperature sensor) Bit 4: TOB1 (Temperature of pressure sensor P1) Bit 5: TOB2 (Temperature of pressure sensor P2) Bit 7 Con (Conductivity sensor) version 5.21-XX.XX only |
2 | CFG_CH0 | version 5.20-XX.XX only Configuration of CH0 (Calculated channel): Byte value (decimal) 0: inactive 1: Difference P1 – P2 2: Difference P2 – P1 3: Square root calculation sqrt(P1), set coefficient Nr. 53 > 0 4: Square root calculation sqrt(P2) , set coefficient Nr. 53 > 0 5: Square root calculation sqrt(P1 – P2) , set coefficient Nr. 53 > 0 6: Square root calculation sqrt(P2 – P1) , set coefficient Nr. 53 > 0 11: Absolute value abs(P1) 12: Absolute value abs(P1 – P2) 13: Line pressure compensated differential pressure (only at factory, add. parameters) 14: straight line curve fitting of P1 (only if P2 is not active, 5.20-12.24 and earlier)
Device has to be
restarted (power
Off/On).
Please note that
for some
settings there
are more
configurations
needed.

3 | CNT_T | Temperature measurement interval in seconds. version 5.20-XX.XX only | |
4 | CNT_TCOMP LP-FILTER | Value of Bit 0 ... 3 (LowNibble): CNT_TCOMP version 5.20-XX.XX only After CNT_T * CNT_TCOMP seconds a temperature compensation will be performed. Value of Bit 4 ... 7 (HighNibble):Low pass filter for P1 and P2. LowpassFilter = 2Bit 4 ... B7 The formula for the low pass filter is given as: LowpassFilter (2 - · 1) P 1 + P P = n -n where: n + 1 2 LowpassFilter Pn+1: new filtered value Pn: actual measured value Pn-1: old filtered value |
5 | | --
6 | | --
7 | FILTER | Filter setting for one conversion: Bit 0: Adaptive filter for P1 and P2 (on / off) Bit 1: Low pass filter for T, TOB1 and TOB2 (on / off) Bit 2.. 4: Over sampling ration OSR = 2^⁽⁸⁺Bit 2 ... 4) version 5.20-XX.XX only Bit 5.. 6: Amount of samples per averaging: 0..3 = 1, 2, 4 or 8 values version 5.20-XX.XX only Factory settings see FILTER_ORG. version 5.20-XX.XX only |
8 | | --
9 | DAC | Analogue output: version5.20-XX.XX only Bit 0: Milli Amperes output (4 .. 20mA) Bit 1: Voltage output Bit 4 = 1: P1 is linked to the analogue output Bit 4 = 0: CH0 is linked to the analogue output Scaling see function 30/31 | (: Bit4) | 5.20-10.40 and earlier. Change of Bit 4 allowed to link the analogue output either to CH0 or P1
10 | UART | UART settings: Bit 0 .. 3: Baud rate Baud rate Value = 0: 9’600baud Baud rate Value = 1: 115’200baud Bit 4: Parity selection. 0: no Parity, 1: Parity enable Bit 5: Parity mode. 0: odd parity, 1: even parity Bit 6: Stop bit. 0: 1 Stop bit, 1: 2 Stop bits version 5.21-XX.XX only | | Device has to be restarted (power Off/On). version 5.20-XX-XX only version 5.21-XX.XX generates a restart -> reinitialised
11 | FILTER_ORG | Factory setting for filter value. version 5.20-XX.XX only | |
12 | STAT | Status of the measurement. See function 73 for details. | |
13 | DEV_ADDR | Device address. Range: 1 .. 255. | |
14 | P-Mode | Type of sensor and calibration. version 5.20-12.XX and later only and 5.21-XX.XX Bit 0 ... 3 (LowNibble) P1: 0: PR (relative), 1: PA (absolute), 2: PAA (absolute) Bit 4 ... 7 (HighNibble) P2: 0: PR (relative), 1: PA (absolute), 2: PAA (absolute) |
15 | SPS | Samples per Second: version 5.21-XX.XX only Range: 5-7 5: 120 SPS 6: 240 SPS 7: 480 SPS |
20 | SDI-12 | version 5.21-14.XX and later only Switch to SDI-12 Mode 0x99 |
28 | ConOn | version 5.21-XX.XX only 0x01: Conductivity powered 0x00: Conductivity unpowered |
31 | ConRange | version 5.21-XX.XX only 0x01: Conductivity Range 1: 0…200uS (0.2mS) 0x02: Conductivity Range 2: 0…2’000uS (2mS) 0x03: Conductivity Range 3: 0…20’000uS (20mS) 0x04: Conductivity Range 4: 0…200’000uS (200mS) |
32 | ConTempCompMode | Conductivity Temperature Compensation Method after DIN/EN 27 888 version 5.21-XX.XX only 0x01: Linear Temperature Compensation @ 25°C 0x02: Linear Temperature Compensation @ 20°C 0x03: Non-linear Temperature Compensation (Table)@ 25°C |
33 | SDI-12_available | version 5.21-13-35 and 5.21-14.35 and later only | |

0x01: Switch to SDI-12 possible 0x00: SDI-12 Wire not available

### 5.6 Function 48 : Initialise and release

Request:

DevAddr | 48 | CRC16_H | CRC16_L

Response:

DevAddr | 48 | Class | Group | Year | Week | BUF | STAT | CRC16_H | CRC16_L

Exception error:

### 3 If message length is incorrect

Note:
Each time the device is switched on by applying the supply voltage or after a break in the power supply, the device must be initialised via this function. Calling a different function will lead to exception error 32.

The following information is returned:

Class | Device ID code
5: | Series 30 digital pressure transmitter (33, 35, 36, 39)
Group | Subdivision within a device class
1: | Series 30 transmitter from 1999 or later
20: | Series 30 transmitter from 2002 or later
21: | Series 30 transmitter version X2
The differences between these devices are defined in italics in the functions.
Year, Week | Firmware version
BUF | Length of the internal receive buffer
STAT | Status information
0: | Device addressed for first time after switching on.
1: | Device was already initialised

### 5.7 Function 66 : Write and read new device address

Request:

DevAddr | 66 | NewAddr | CRC16_H | CRC16_L

Response:

DevAddr | 66 | ActAddr | CRC16_H | CRC16_L

Exception error:

### 3 If message length is incorrect 32 If device is not yet initialised

Note:
This function programmes the device addresses to NewAddr. The address is returned in ActAddr as confirmation. It is to be ensured that the new address NewAddr is not already in use by another bus user.

Permissible addresses: 1 .. 255. Address 250 is transparent. This means that every device, irrespective of the set address, will respond to address 250. Consequently, transparent DevAddr = 250 may only be used in stand-alone operating mode!

For the purpose of reading the device address when the address is not known, for example, the value 250 is transferred as DevAddr and the value 0 is transferred as NewAddr. The current address is then returned in response.

### 5.8 Function 69 : Read serial number

Request:

DevAddr | 69 | CRC16_H | CRC16_L

Response:

DevAddr | 69 | SN3 | SN2 | SN1 | SN0 | CRC16_H | CRC16_L

Exception errors:

### 3 If message length is incorrect

32 If device is not yet initialised.

Note:
The serial number is allocated at the factory. It consists of 4 bytes unsigned integer and is calculated as follows:

SN = 256 ³ * SN3 + 256 ² * SN2 + 256 * SN1 + SN0

### 5.9 Function 73 : Read value of a channel (floating point)

Request:

DevAddr | 73 | CH | | CRC16_H | CRC16_L

Response:

DevAddr | 73 | B3 | B2 | B1 | B0 | STAT | CRC16_H | CRC16_L

Exception errors:

### 2 If CH > 5 version 5.20-XX.XX and if CH > 11 version 5.21-XX.XX

### 3 If message length is incorrect 32 If device is not yet initialised

Note:
A device can measure up to five signals (channels):
version 5.20-XX.XX: Two independent pressure sensors P1 and P2, as well as the temperatures of pressure sensors TOB1 and TOB2 and an additional temperature sensor T. The temperatures of the pressure sensors (TOB1, TOB2) are required for temperature compensation of the pressure signal.
version 5.21-XX.XX: One pressure sensor P1, as well as the temperatures of pressure sensors TOB1 and an additional temperature sensor T. Optional a conductivity sensor is available and ConTc and ConRaw can be measured as well. The temperature of the pressure sensor (TOB1) is required for temperature compensation of the pressure signal.
Please use function 32 to get the information which Channels are active.
CH0 is a calculated channel whose mode of functioning is defined in function 32 / 33.
On a standard pressure transmitter, only channels P1 and TOB1 are available. You can read out which channels are active via function 32.

The measured value is returned in IEEE754 format (4-byte B0 ... B3).

CH | Name | Description | Unit
0 | CH0 | Calculated channel (see function 32,33 version 5.20-XX.XX only) | *
1 | P1 | Pressure from pressure sensor 1 | bar
2 | P2 | Pressure from pressure sensor 2 | bar
3 | T | Additional temperature sensor | °C
4 | TOB1 | Temperature of pressure sensor 1 | °C
5 | TOB2 | Temperature of pressure sensor 2 | °C
10 | ConTc | Conductivity Temperature Compensated version 5.21-XX.XX only | mS/cm
11 | ConRaw | Conductivity Raw Value version 5.21-XX.XX only | mS/cm
* Dependent on definition in function 32.

The STAT byte contains the current status.

Bit position | .7 | .6 | .5 | .4 | .3 | .2 | .1 | .0
Name | /STD | ERR2 | TOB2 | TOB1 | T | P2 | P1 | CH0

A set /STD bit indicate whether the transmitter is in Power-up mode, otherwise it is in Standard mode.

A set ERR2 bit denotes that a computation error has occurred in the calculation process for the analogue output. This occurs if the analogue Signal is in saturation (depends on the scaling). version5.20-XX.XX only

A set CH0, P1, P2, T, TOB1, TOB2 bit indicates that a measuring or computation error has occurred in the channel concerned.

For details in error-handling see chapter Error handling and recognition!

Function 74 : Read value of a channel (32bit integer)

Request:

DevAddr | 74 | CH | CRC16_H | CRC16_L

Response:

DevAddr | 74 | B3 | B2 | B1 | B0 | STAT | CRC16_H | CRC16_L

Exception errors:

### 2 If CH > 5 3 If message length is incorrect

4 Class.Group -Year.Week = 5.20-5.50 and earlier: If a channel is in overflow/underflow/inactive state or the data is invalid.
For newer versions: overflow/underflow/inactive state is showed by value. See Chapter 6.3

### 32 If device has not yet been initialised

Note:
Same as function 73, but values as 4-byte integer (long) B0 .. B3, where B3 is MSByte. The resolution is reduced to 0.1mbar. Unit: CH0: *10⁻⁵
P1 and P2: Pascal (1Pa = 10⁻⁵ bar).
T, TOB1 and TOB2: 0.01°C
ConTC and ConRaw are not available with F74

Status-Byte (STAT): See function 73.
For details in error-handling see chapter Error handling and recognition!

### 5.10 Function 95 : Commands for setting the zero point

Requests:

Request a:

DevAddr | 95 | CMD | | CRC16_H | CRC16_L

Request b with set point:

DevAddr | 95 | CMD | B3 | B2 | B1 | B0 | CRC16_H | CRC16_L
where B3:B0: Floating-point number IEEE754 format (4-byte B0 ... B3) for the set point.

Response:

DevAddr | 95 | 0 | | CRC16_H | CRC16_L

Exception errors:

### 1 If in Power-up mode

If data value is incorrect (NaN, INF, NINF) Class.Group 5.21-XX.XX only

### 2 If CMD invalid 3 If message length incorrect 32 If device is not yet initialised

Note:
The following actions can be carried out with this function:
CMD | Meaning
0 Set zero point of P1 1 Reset zero point of P1 to standard value 2 Set zero point of P2 3 Reset zero point of P2 to standard value 4 --5 --6 Set zero point of CH0 7 Reset zero point of CH0 to standard value 8 Set zero point of T version 5.21-XX.XX only 9 Reset zero point of T to standard value version 5.21-XX.XX only 10 Set zero point of TOB1 version 5.21-XX.XX only 11 Reset zero point of TOB1 to standard value version 5.21-XX.XX only 12 Set zero point of TOB2 version 5.21-XX.XX only 13 Reset zero point of TOB2 to standard value version 5.21-XX.XX only

CMD 0, 2, 6, 8, 10, 12:
Zero point values for pressure channels P1, P2 and the calculated channel CH0 and T, TOB1, TOB2. These values can also be read via function 30 and written via function 31.
Request a: | The zero point is calculated such that the current measured value = 0.0.
Request b: | The zero point is calculated such that the current measured value equals the set point (B3:B0).

CMD 1, 3, 7, 9, 11, 13: Reset zero point to factory setting
The zero point values are reset to 0.

### 5.11 Function 100 : Read configuration

Request:

DevAddr | 100 | Index | CRC16_H | CRC16_L

Response:

DevAddr | 100 | PARA0 | PARA1 | PARA2 | PARA3 | PARA4 | CRC16_H | CRC16_L

Exception errors:

### 2 If index > 8 3 If message length is incorrect 32 If device is not yet initialised

Note:
This function supplies the information about the configuration of the device. Please use Function 32 instead of this function for devices of Class.Group 5.20-5.24 and earlier. With function 32/33 you have access to a single parameter instead of all five parameters.
A pressure transmitter can read two independent pressure sensors (P1 and P2), plus the temperatures of the respective pressure sensors (TOB1 and TOB2) and an independent temperature ( T ).
Index | Para0 | Para1 | Para2 | Para3 | Para4
0 | | UART | FILTER_ORG
2 | CFG_P | CFG_T | CFG_CH0 * | CNT_T | High Nibble | Low Nibble* LP-Filter | CNT_TCOMP
3 | | | FILTER | | DAC *
*: Not for Class.Group 5.21-XX.XX

For details see description in function 32 / 33. For change the configuration use function 33.

### 6 Appendix

### 6.1 Interface converter

The serial RS232 interface or the USB interface can be used for connection to a PC. KELLER offers converters for this purpose. Various other products are commercially available, however. The following requirements apply when working with KELLER software:
- The converter must control transmit / receive switch-over automatically.
- KELLER converters feature a hardware echo, i.e. the transmitted message is received again immediately as an echo. This echo is required by some KELLER software programmes.

### 6.2 Floating-point format IEEE754

As data transmission is effected byte-wise (8-bit data), the floating-point values are represented as follows:
B0: Bit 0..7; | B1: Bit 8..15, | B2: Bit 16..23, | B3: Bit 24..31

Representation in accordance with IEEE754:
B3 DATA H (Reg. 0) | B2 DATA L (Reg. 0) | B1 DATA H (Reg. 1) | B0 DATA L (Reg. 1)
b01000001 (0x41) | b00101001 (0x29) | b00000010 (0x02) | b11011110 (0xDE) | Valid Number
b01111111 (0x7F) | b10000000 (0x80) | b00000000 (0x00) | b00000000 (0x00) | ∞ / Overflow
b11111111 (0xFF) | b10000000 (0x80) | b00000000 (0x00) | b00000000 (0x00) | -∞ / Underflow
bx1111111 (0xFF) | b11111111 (0xFF) | b11111111 (0xFF) | b11111111 (0xFF) | Not a Number

1 bit Sign + 8 bit Exponent + 23 bit Mantis = 32 bit

Calculation of the value transmitted:

127
2

( 1) (1.0 23 ) 2

= - | · | + | ·
S | M | E V

0 = 0
10000010 = 130
01010010000001011011110 = 2687710

-1

0 * (1.0 + 2687710/8388608) * 2¹³⁰⁻¹²⁷ = 10.5631999969482421875

These values directly show the value in the requested unit [bar] or [°C].
- 10.5632 bar

Usage of Keller software:
If you use the DLL which is available from KELLER, you do not need to carry out conversion, as this is encapsulated in the DLL. If you wish to address the devices directly, however, you must convert the individual bytes into a floating-point value.
To obtain a floating-point value from the individual bytes, proceed as follows:
1. Define data structure in which an array of 4 bytes and a 32-bit floating-point value is defined at the same memory location.
2. Write the bytes into the byte array.
3. Read out the floating-point value.
You do not need to carry out any actions, therefore, as the computer attends to interpretation. Some microcontrollers have a different data structure for floating-point values. In such cases, adaptation is necessary.

### 6.3 Error handling and recognition

The electronic unit can read five signals: pressure values from two pressure sensors (P1, P2), temperature values from both of these pressure sensors (TOB1, TOB2) and temperature value from one additional temperature sensor (T). Additionally, out of these values, other values can be calculated (CH0). These values are described as channels in this documentation.
To check if the channels are active one may use function F32 (or MODBUS addresses 0x0204-0x0206) (refer to according chapter).

Measuring range
The signals are being measured with an analogue to digital converter (ADC). The measuring range is limited upwards and downwards.
For the pressure signals P1 and P2 the limitation is depending on the compensated pressure range, which can be read out with function 30 (as well as MODBUS function 3 [range 0x03xx] from version 5.20-10.XX and later and 5.21-XX.XX).
Readable range: (pressure range minimum – 10%) up to (pressure range maximum + 10%)
Is the pressure below or above this range, then the bit in the Status-Byte will be set. The measured value itself is no longer valid when the Status-Bit is set.

Dependencies
P1 and P2 are temperature-compensated and therefore they are depending on temperature. Channel CH0 is always depending on P1 and / or P2 and on a temperature channel. Is there a fault in one of these dependencies so the depending channel will follow accordingly.

### 6.3.1 What is new in version 5.20-10.40 (and later) and 5.21-XX.XX

Version 5.20-10.40 (available end of 2010) and later will display additionally to the Status-Bit also an error in the value itself. The format follows the special indications according to floating point arithmetic: NaN, +Inf (ovl), -Inf (uvl). See chapter floating-point Format IEEE754.

| CH0 | P1 / P2 | TOB1 / TOB2
NaN | Dependency error (P1, P2 = NaN or +/-Inf) | +/-Inf in compensating T-channel | -
+Inf | - | ADC value out of range (Overflow) | ADC value out of range (Overflow) or T > 300 °C
-Inf | - | ADC value out of range (Underflow) | ADC value out of range (Underflow) or T < - 70°C
0.000 | Sqrt: ( p < Pcutoff ) | - | -

The values NaN, +Inf and –Inf are defined in the IEEE754 standard and are described in chapter Floating-point format IEEE754.

NaN is also shown, when the requested channel is not active. In this case, the Staus-Bit is not set.

Special Integer Values (F74, F3):

| 32bit signed integer | 16bit signed integer
NaN, +Inf | 2147483647 (0x7FFFFFFF) | 32767 (0x7FFF)
-Inf | -2147483648 (0x80000000) | -32768 (0x8000)

### 6.3.2 Analogue Output

The analogue output has to transfer the error states described in the former chapter and therefore additional analogue states were introduced. The graph below shows the transfer function between pressure (in this example the analogue output is a function of P – however it could also be some other mathematical function using CH0). The black line shows the transfer function for a positive DAC-gain. The Sigerror is independent of any scaling function and represents an internal error state (source has NaN, see table above).

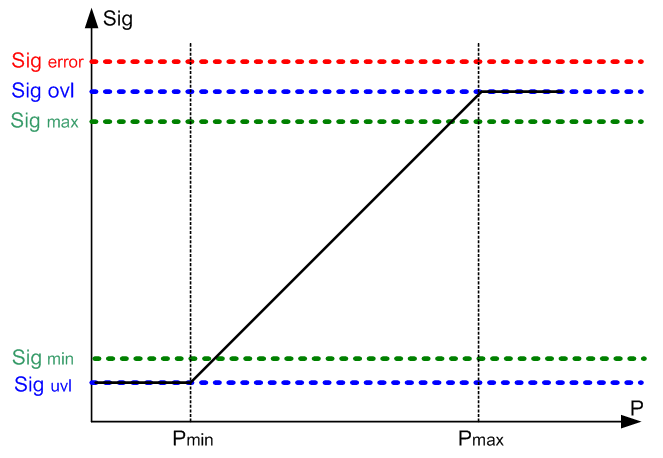
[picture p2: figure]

The following table shows possible analogue values for different hardware types:

| 0-10 V, (0..5V) | 0-2.5 V | 4-20 mA | Dig. representative
Sig error | 11.6 V | 2.9 V | 22.5 mA | NaN
Sig ovl | 11 V | 2.75 V | 21.8 mA | +Inf
Sig max | 10 V | 2.5 V | 20 mA | value
Sig min | 0 V | 0 V | 4 mA | value
Sig uvl | -1 V | -0.3 V | 3.3 mA | -Inf

### 6.4 Calculation of the CRC16 checksum

The checksum can either be calculated or derived from a table.
Here is an example of CRC16 calculation in C:

//////////////////////////////////////////////////////////////////////////
// CRC-16 calculation in C
//
// Calculation of CRC-16 checksum over an amount of bytes in the serial buffer.
// The calculation is done without the 2byte from crc16 (receive-mode).
// SC_Buffer[]: Byte-Buffer for the serial interface. Type: unsigned char (8bit)
// SC_Amount : Amount of Bytes which should be transmitted or are received (without CRC16) //
//////////////////////////////////////////////////////////////////////////
void CalcCRC16(unsigned char* CRC_H, unsigned char* CRC_L)
{
// locals
unsigned int Crc;
unsigned char n, m, x;

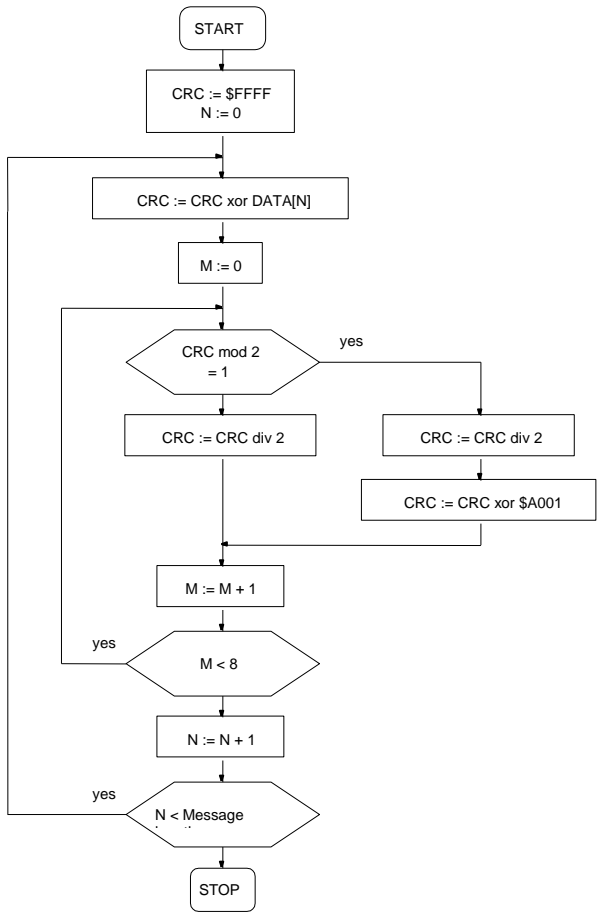
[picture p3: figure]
CRC := $FFFF N := 0; CRC mod 2 = 1; CRC := CRC div 2; CRC := CRC xor $A001; N < Message; START; STOP; CRC := CRC xor DATA[N]; yes

// initialisation
Crc= 0xFFFF;
m= SC_Amount;
x= 0;

// loop over all bits
while(m>0)
{
Crc^= SC_Buffer[x];
for(n=0; n<8; n++)
{
if(Crc&1)
{
Crc>>= 1;
Crc^= 0xA001;
}
else
Crc>>= 1;
}
m--;
x++;
}
// result
*CRC_H= (Crc>>8)&0xFF;
*CRC_L= Crc&0xFF;
}// end CalcCRC16

This results in the following calculation for function 48 with device address 250: CRC16_H= 4, CRC16_L= 67.

Examples showing use based on a table are to be found in the MODBUS documentation at: http://www.modbus.org

### 6.5 Changes

- Document version 2.1, 19. October 2005: New function 32 and 33 for device Class.Group -Year.Week = 05.24 and earlier, F75: cancelled.
- Document version 2.2, 16. August 2006:
Description for function 32/33 revised. Function 101 added. Formula for scaling of the analogue output corrected.
- Document version 3.0, 20. December 2010:
Added Modbus (chapter 4) support for Class.Group=5.20-10.XX
Modbus Implementation of Functions (3,6,8 and 16) with support of all functions covered by the Keller Bus protocol. Added chapter error handling and recognition
Modified chapter “Floating-point format IEEE754”
- Document version 3.1, 14. August 2012:
Added changements of Class.Group=5.20-12.28
- Document version 3.2, 12. August 2013:
New device family Class.Group=5.21-XX.XX added.
- Document version 3.3, 1. November 2014:
Commands for Conductivy Sensor added in Class.Group=5.21-XX.XX.
- Document version 3.4, 1. June 2015:
New commands for Conductivity Sensor added in Class.Group=5.21-XX.XX.
- Document version 3.5, 27. January 2017:
Default added for Baudrate and Bus Address

### 6.6 Software versions

An overview of the released versions for Class.Group 5.20-XX.XX:

Version Year.Week | Date of production | Major changements
2.40 | 2002..2003 | Base version
3.50 | 2003 .. 2006 | -CH0: add option Line pressure compensation
5.50 | 2006 .. 2010 | -Hardware redesign to increase robustness under EMC - add Low pass Filter and adaptive Filter for pressure channels - Switch2 option cancelled - only two temperature channels possible: TOB1 and TOB2 or T - sqrt calculation without scaling factor - add function F32 and F33 for configuration access known issue: CRC of exception code using MODBUS F3 is wrong
10.40 | 2011…2012 | - | Improved error handling: see error handling and recognition
- Switch option: cancelled
- CH0: Curve fitting added (CFG_CH0= 14), SF6 calculation: cancelled (CFG_CH0=7..10) MODBUS protocol:
- CRC16 in case of an exception corrected
- F3: access to all registers as in the KELLER protocol (Information and config values)
- Serial buffer increased from 10 to 13Bytes → readout of 2 values possible in one task
- F6, F8, F16 added: Configuration an calibration also with MODBUS
known issue:
- MODBUS F3 0x0010 ..0x001A: not usable
- CH0 scale (Coeff 70 and 71) must be default (Nr.70 = 0.00, Nr. 71 = 1.00)
12.28 | Aug. 2012.. | - | CH0 scaling: corrected
- MODBUS F3:
| | | 0x020E, 0x020F: Read firmware version added Int 16Bit values 0x0010 .. 0x0015 compatible with version 5.20-5.50 0x0020 .. 0x002A: integer 32bit for process values added

An overview of the released versions for Class.Group 5.21-XX.XX:

Main differences between Group 20 and the new added Group 21.

- Group 21 has no analogue output only digital communication
- Group 21 has a SDI-12 communication interface and is able to work as SDI-12 device
- Group 21 has a higher ADC resolution for pressure and temperature channel
- Group 21 has a larger buffer size for RS485 communication.
Version Year.Week | Date of production | Major revision
13.33 | August 2013 | Base version
13.35 | August 2013 | Implementation of HW identification
14.35 | August 2014 | Implementation of the conductivity sensor
15.45 November | 2015 | Adaption of threshold values of conductivity

### 6.7 Support

We are pleased to offer you support in implementing the protocol. Use our free PC-software CCS30 for communication and configuration. Also divers for LabView, C#, etc. are available on our website: http://www.keller-druck.com
KELLER AG für Druckmesstechnik
St. Gallerstrasse 119 • CH-8404 Winterthur
Tel: ++41 52 235 25 25
http://www.keller-druck.com

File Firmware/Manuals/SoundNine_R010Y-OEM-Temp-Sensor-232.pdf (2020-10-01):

R010Y

www.soundnine.com

# OEM Temperature Sensor

There are currently two interface types:
1. RS232 Serial
2. Logic level serial (3.3v)

Connecting a logic level device to a RS232 serial port may damage the sensor.

## Connecting to the Sensor

Use the serial port settings listed on the right. The sensor’s default mode is sampling at 2Hz.

### Output Format

This is a sample of sensor output data:

2464.082026, 19.818856
2464.078062, 19.818895
2464.080833, 19.818868
2464.077906, 19.818897
The first number is thermistor resistance in ohms, the second is

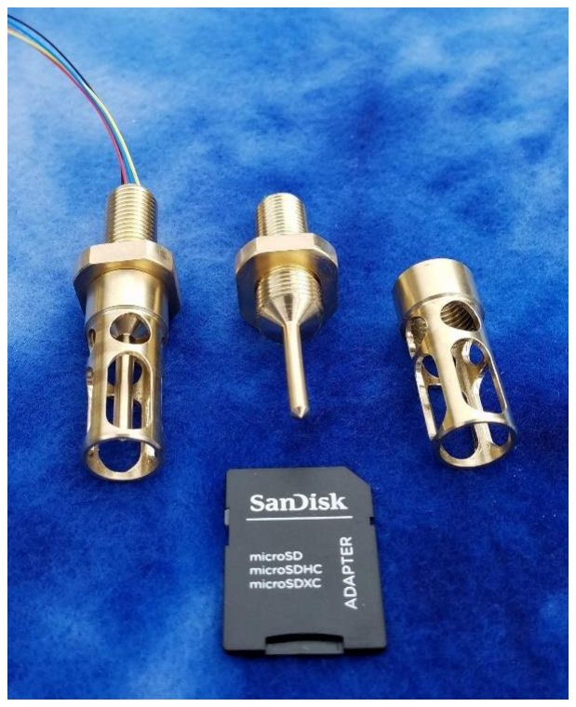
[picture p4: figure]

temperature in degrees. The temperature calculation uses calibration coefficients stored internally.

### Commands

The sensor uses a simple command line interface. Commands are
lower case. Type the command, then press enter, or send CR (0x0D). LF characters (0x0A) are ignored.

STOP
Stops sampling.

START
Resumes sampling. The sensor will start outputting data in the format shown above at the programmed period (see period command below).

PERIOD
Sets the sample period in milliseconds. The range is 500ms to 3600000 ms (1 hour). The period setting is volatile – it will revert to 500ms if the sensor is disconnected.

S9>period 500
OK

### Serial Port Settings

9600 Baud
8 bits
No parity
1 stop bit
No flow control

### Terminal Program Settings

CR (‘\r’) for new line
LF (‘\n’) not required

OEM Temperature Sensor
Connecting to the Sensor

SAMPLE
Takes a sample immediately and returns the result.

S9>sample
2464.077906, 19.818897
OK

VER
Reports the sensor serial number (referred to as a Module ID or MID), the calibration coefficients, reference resistor value and the firmware version.

S9>ver
MID=T003
C0=0.000855
C1=0.000293
C2=0.000000
C3=0.000000
R0=10000.000
UID=000000000F0F1A08535722E74FBC90B1 S9T0 V0.45
OK

### Specifications

Temperature
Range: | -5 to +45°C
Initial Accuracy: ±0.005°C (-5 to +35°C)
Stability: | 0.00025°C/month
Resolution: | 0.0001°C
Time constant: 800 milliseconds (still water)

Power: 3.3VDC to 18.5VDC
Housing: Brass
Pressure: 5000PSI

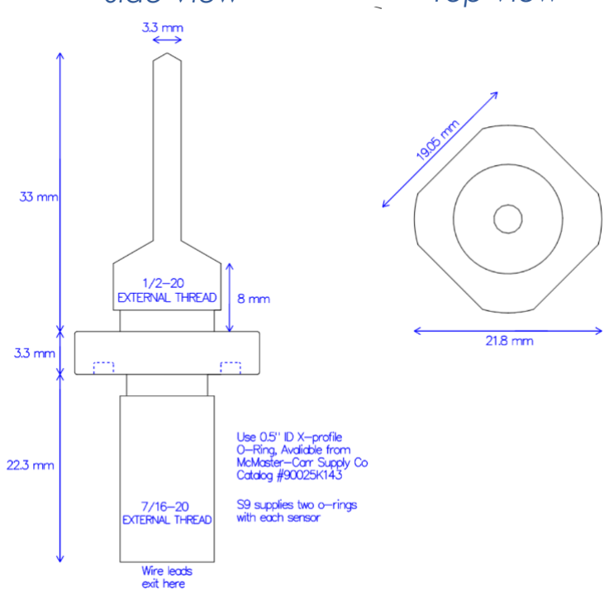
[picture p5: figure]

Side View | Top View | Sensor Guard Side View

Recommended
Mate Pattern

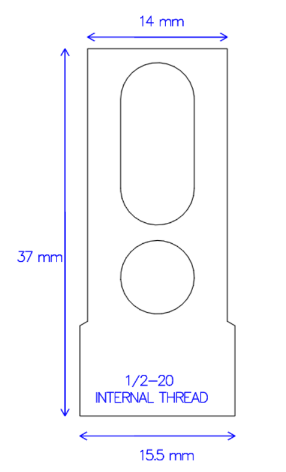
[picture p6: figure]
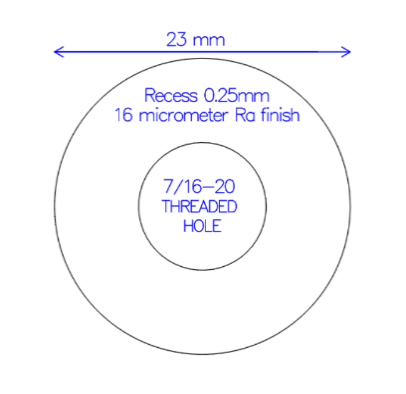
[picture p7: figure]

OEM Temperature Sensor
Connecting to the Sensor

Connect DB9F pin 2 to TXO; pin 3 to RXI, pin 5 to GND.

Connect 3.3V to 12V power supply to V+ and GND.

Current draw is approximately 10mA.

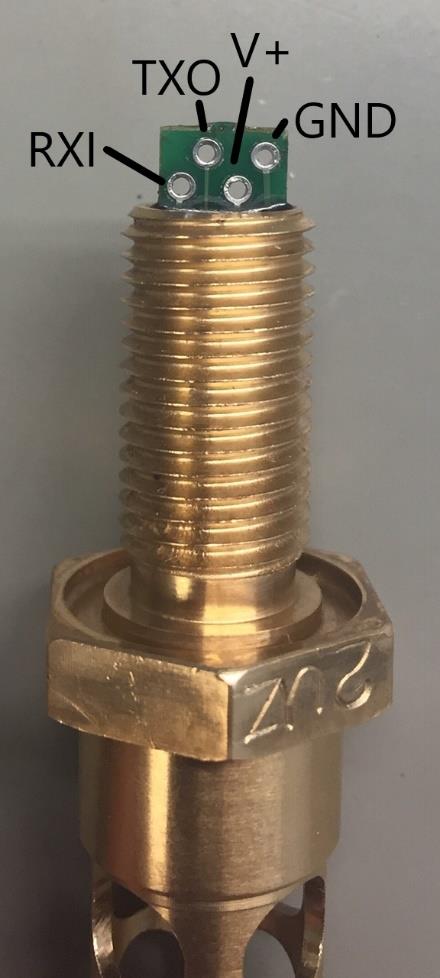
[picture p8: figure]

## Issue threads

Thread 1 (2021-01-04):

Change GPS module

MCasari-PMEL, 2021-01-04:
## Issue
GPS Module (u-blox ZOE-M8Q) is not hand-solderable.

## Fix
Change to MAX-M8Q instead

Closed 2024-07-31.

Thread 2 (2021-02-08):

J14 not co-located with Iridium modem

MCasari-PMEL, 2021-02-08:
## Issue

Connector J14 is located on the opposite side of tall components from Iridium Modem.  J14 is the U.fl connector which routes the antenna to the modem, and should be as short as possible.

## Fix

Move J14 to a position directly adjacent to Iridium modem.  Use the modem as a reference for where that signal comes from and how to keep it short.  Also look up preterminated cables to add to BOM, and see standard cut lengths.

Closed 2024-07-31.

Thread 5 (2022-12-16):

Add pressure sensor to board for diagnostic

MCasari-PMEL, 2022-12-16:
# Add pressure sensor
Add a pressure sensor for pre-deployment diagnostics

## Parts to consider
MS5837
BME280
Any other I2C/SPI

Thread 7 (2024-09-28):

RF Issues

jkurina86, 2024-09-28:
- We are routing the Iridium directly from the module to the antenna, so it doesn't need any connectors on the board.
- The ublox EVA-M8 series hardware integration manual (pgs 20-21) states the following regarding the antenna routing:
> Add a ground plane underneath the GNSS module to reduce interference. This is especially important for the RF input line.
> For improved shielding, add as many vias as possible around the micro strip/coplanar waveguide, around the serial communication lines, underneath the GNSS module, etc.
> **The micro strip / coplanar waveguide must be 50 Ω** and be routed in a section of the PCB where minimal interference from noise sources can be expected. **Make sure that there is only GND around and under the RF line**.

These instructions were not followed and have resulted in degraded GPS performance. To resolve this we need to do the following:
- Use a copper-pour on the top layer and ensure that the ground copper layer is present beneath the RF trace to create a coplanar RF waveguide. Use via stitching on both sides of the waveguide.
- https://www.microwaves101.com/calculators/864-coplanar-waveguide-calculator use this to calculate the RF trace width and length to impedance match ZO=50 Ohms. Use ER=4.7 for FR-4 board. Substrate Thickness (H) is in mils and our boards are set to approximately 18.9 mils thick.

noahlawrence-slavas, 2024-10-21:
Is the ground plane still needed, I was confused vs the last hallway conversation we had about this?

jkurina86, 2024-10-21:
Yes. The Ublox datasheet mentions the ground plane beneath the trace being used in the calculation of the trace RF calculations. Below is a cross-section illustration of a standard coplanar waveguide:

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

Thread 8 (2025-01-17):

verify that temperature data can go negative

noahlawrence-slavas, 2025-01-17:
with flag or other implementation.  test in freezer, if not working, then institute the same intelligence that Scott uses on the Pop-up.

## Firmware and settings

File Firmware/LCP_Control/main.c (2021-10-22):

///
/// @file artemis_main.c
///

#include "main.h"
#include "S9_temp.h"
#include "bsp_uart.h"

#include "artemis_debug.h"
#include "artemis_mcu.h"
//#include "artemis_scheduler.h"
//#include "artemis_time.h"
//#include "artemis_pa9ld.h"
//#include "artemis_ublox_i2c.h"
#include "artemis_supercap.h"
#include "ublox.h"

#include "control.h"
#include "piston.h"
#include "sensors.h"
#include <stdlib.h>

//#define TEST_UBLOX  true
//#define TEST_SUPERCAP true
#define TEST_S9 true

int main(void)
{
    // initialize mcu features
    artemis_mcu_initialize();

    // initialize debug features
    artemis_debug_initialize();

    // initialize time functions
    artemis_time_initialize();

    // initialize the scheduler
//    artemis_scheduler_initialize();

    // run the application
//    artemis_scheduler_run();
    
    // initialize the piston 
//    PIS_initialize();
    
//#ifdef TEST_S9
//    /** Init Soundnine Temperature Sensor */
//    S9T_init(BSP_UART_COM1, &g_AM_BSP_GPIO_COM1_POWER_PIN, AM_BSP_GPIO_COM1_POWER_PIN);
//    S9T_enable();
//    float p, r, t;
//#endif
    
    
//#ifdef TEST_UBLOX
//    /** Init GPS */
//    UBLOX_initialize(UBLOX_COM_I2C, UBLOX_MSG_UBX, UBLOX_MSG_UBX, 1);
//    UBLOX_Nav_t gps = {0};
//#endif
//    
//#ifdef TEST_SUPERCAP
//    artemis_sc_initialize();
//    
//    if(artemis_sc_power_startup())
//    {
//      printf("Success in starting supercap charging!\n");
//    } else {
//      printf("Failed to start supercap charge\n");
//    }
//#endif
//    PIS_retract();
//    PIS_extend();
//    am_hal_systick_delay_us(2500000);
//    PIS_stop();
//    am_hal_systick_delay_us(2500000);
//    PIS_retract();
//    while(true)
//    {
//#ifdef TEST_UBLOX
//      UBLOX_read_nav(&gps);
//      printf("GPS Fix = %u\n", gps.fix);
//
//      if(gps.fix)
//      {
//        printf("Lat=%.7f, Lon=%.7f, Alt=%.3f\n", gps.position.lat, gps.position.lon, gps.position.alt);
//      }
//#endif
//      
//#ifdef TEST_S9
//    S9T_Read(&t, &r);
//    printf("t=%.3f, r=%.3f\n", t, r); 
//#endif
//    
//
//    }
    SENS_initialize();
    TaskHandle_t xDepthHandle = NULL;
    xTaskCreate((TaskFunction_t) task_depth, "depth", 128, NULL, 1, &xDepthHandle);
    vTaskStartScheduler();
    float d, r;
    while(1)
    {
      
      SENS_get_depth(&d, &r);
      printf("d=%0.3f\n", d);
    }
    
    
    
    return(EXIT_SUCCESS);
}

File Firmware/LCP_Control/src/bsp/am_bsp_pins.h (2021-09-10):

//*****************************************************************************
//
//  am_bsp_pins.h
//! @file
//!
//! @brief BSP pin configuration definitions.
//!
//! @addtogroup BSP Board Support Package (BSP)
//! @addtogroup apollo3_bsp BSP for the Apollo3 EVB.
//! @ingroup BSP
//! @{
//
//*****************************************************************************

//*****************************************************************************
//
// Copyright (c) 2019, Ambiq Micro
// All rights reserved.
// 
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
// 2. Redistributions in binary form must reproduce the above copyright
// notice, this list of conditions and the following disclaimer in the
// documentation and/or other materials provided with the distribution.
// 
// 3. Neither the name of the copyright holder nor the names of its
// contributors may be used to endorse or promote products derived from this
// software without specific prior written permission.
// 
// Third party software included in this distribution is subject to the
// additional license terms as defined in the /docs/licenses directory.
// 
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
// This is part of revision 2.2.0-hotfix-2.2.1 of the AmbiqSuite Development Package.
//
//*****************************************************************************

#ifndef AM_BSP_PINS_H
#define AM_BSP_PINS_H

#include <stdint.h>
#include <stdbool.h>
#include "am_mcu_apollo.h"

#ifdef __cplusplus
extern "C"
{
#endif

//*****************************************************************************
//
//  LED_GREEN pin: This pin is the Green LED pin (LED1).
//
//*****************************************************************************
#define AM_BSP_GPIO_LED_GREEN           	31
extern const am_hal_gpio_pincfg_t       g_AM_BSP_GPIO_LED_GREEN;

//*****************************************************************************
//
//  LED_RED pin: This pin is the Red LED pin (LED2).
//
//*****************************************************************************
#define AM_BSP_GPIO_LED_RED             	32
extern const am_hal_gpio_pincfg_t       g_AM_BSP_GPIO_LED_RED;

//*****************************************************************************
//
//  LED_BLUE pin: This pin is the Blue LED pin (LED3).
//
//*****************************************************************************
#define AM_BSP_GPIO_LED_BLUE            	29
extern const am_hal_gpio_pincfg_t       g_AM_BSP_GPIO_LED_BLUE;

//*****************************************************************************
//
//  SC_NSHDN pin: This pin is the supercapacitor shutdown (negative) pin.
//
//*****************************************************************************
#define AM_BSP_GPIO_SC_NSHDN            	0
extern const am_hal_gpio_pincfg_t       g_AM_BSP_GPIO_SC_NSHDN;

//*****************************************************************************
//
//  SC_PGOOD pin: This pin is the supercapacitor power-good pin.
//
//*****************************************************************************
#define AM_BSP_GPIO_SC_PGOOD            	28
extern const am_hal_gpio_pincfg_t       g_AM_BSP_GPIO_SC_PGOOD;

//*****************************************************************************
//
//  SC_ON pin: This pin is the supercapacitor on pin.
//
//*****************************************************************************
#define AM_BSP_GPIO_SC_ON               	1
extern const am_hal_gpio_pincfg_t       g_AM_BSP_GPIO_SC_ON;

//*****************************************************************************
//
//  CONSOLE_UART_TX pin: This pin is the Console UART transmit pin.
//
//*****************************************************************************
#define AM_BSP_GPIO_CONSOLE_UART_TX     	48
extern const am_hal_gpio_pincfg_t       g_AM_BSP_GPIO_CONSOLE_UART_TX;

//*****************************************************************************
//
//  CONSOLE_UART_RX pin: This pin is the Console UART receive pin.
//
//*****************************************************************************
#define AM_BSP_GPIO_CONSOLE_UART_RX     	49
extern const am_hal_gpio_pincfg_t       g_AM_BSP_GPIO_CONSOLE_UART_RX;

//*****************************************************************************
//
//  IRIDIUM_ON pin: This pin is the Iridium Module Power pin.
//
//*****************************************************************************
#define AM_BSP_GPIO_IRIDIUM_ON          	4
extern const am_hal_gpio_pincfg_t       g_AM_BSP_GPIO_IRIDIUM_ON;

//*****************************************************************************
//
//  IRIDIUM_RING_IND pin: This pin is the Iridium Ring Indicator pin.
//
//*****************************************************************************
#define AM_BSP_GPIO_IRIDIUM_RING_IND    	22
extern const am_hal_gpio_pincfg_t       g_AM_BSP_GPIO_IRIDIUM_RING_IND;
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

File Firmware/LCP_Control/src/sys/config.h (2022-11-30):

#define PI                      ( 3.14159265359)

#define SYS_SMALL_PISTON_DIAMETER         ( 2.25f )
#define SYS_SMALL_PISTON_MAX_LENGTH       ( 6.00f )
#define SYS_LARGE_PISTON_DIAMETER         ( 4.50f ) 
#define SYS_LARGE_PISTON_MAX_LENGTH       ( 6.0f )
#define SYS_HOUSING_DIAMETER                ( 4.88f )
#define SYS_HOUSING_LENGTH                  ( 35.0f )


#define SMALL_PISTON_DIAMETER     (SYS_SMALL_PISTON_DIAMETER)
#define SMALL_PISTON_MAX_LENGTH   (SYS_SMALL_PISTON_MAX_LENGTH)
#define SMALL_PISTON_MAX_VOLUME   (SMALL_PISTON_DIAMETER * PI * SMALL_PISTON_MAX_LENGTH)
#define LARGE_PISTON_DIAMETER     (SYS_LARGE_PISTON_DIAMETER)
#define LARGE_PISTON_MAX_LENGTH   (SYS_LARGE_PISTON_MAX_LENGTH)
#define LARGE_PISTON_MAX_VOLUME   (LARGE_PISTON_DIAMETER * PI * LARGE_PISTON_MAX_LENGTH)
#define HOUSING_DIAMETER          (SYS_HOUSING_DIAMETER)
#define HOUSING_LENGTH            (SYS_HOUSING_LENGTH)
#define HOUSING_VOLUME            (HOUSING_DIAMETER * PI * HOUSING_LENGTH)
#define SYSTEM_MAX_VOLUME         (HOUSING_VOLUME + SMALL_PISTON_MAX_VOLUME + LARGE_PISTON_MAX_VOLUME + 0.01)
#define SYSTEM_MIN_VOLUME         (HOUSING_VOLUME - 0.01)
#define SYSTEM_MIN_LENGTH         (0.0f)
#define SYSTEM_MAX_LENGTH         (SMALL_PISTON_MAX_LENGTH + LARGE_PISTON_MAX_LENGTH)

#define DRAG_PLATE_DIAMETER         ( 8.0f )
#define DRAG_PLATE_RADIUS           ( DRAG_PLATE_DIAMETER /2 )
#define DRAG_PLATE_AREA             ( PI * DRAG_PLATE_DIAMETER * DRAG_PLATE_DIAMETER )

#define SYSTEM_WEIGHT_EST           ( 25.0 )
#define SYSTEM_CROSSSECTION_AREA    ( DRAG_PLATE_AREA )

#define CYLINDER_DRAG_COEFF         ( 0.81 )

#define SYSTEM_DENSITY_SEAWATER     ( 1033.0 )
#define SYSTEM_VOLUME_MIN           ( HOUSING_VOLUME)
#define SYSTEM_VOLUME_MAX           ( HOUSING_VOLUME + SMALL_PISTON_MAX_VOLUME )
#define SYSTEM_VOLUME_RESERVE       ( LARGE_PISTON_MAX_VOLUME )
#define SYSTEM_NEUTRAL_BUOYANCY     ( 1025 ) 
#define SYSTEM_RISE_RATE_MAX        ( 0.075 )
#define SYSTEM_RISE_RATE_SETPOINT   ( 0.100 )
#define SYSTEM_RISE_RATE_MIN        ( 0.125 )
#define SYSTEM_FALL_RATE_MAX        ( 0.125 )
#define SYSTEM_FALL_RATE_MIN        ( 0.075 )
#define SYSTEM_FALL_RATE_SETPOINT   ( 0.100 )


#define SYSTEM_PROFILER_PARK_DEPTH              ( 30 )
#define SYSTEM_PROFILER_PARK_DEPTH_ERR          ( 2 ) 
#define SYSTEM_PROFILER_PARK_DURATION_MIN       ( 10 )
#define SYSTEM_PROFILER_PARK_DURATION_SEC       ( SYSTEM_PROFILER_PARK_DURATION_MIN * 60 )
#define SYSTEM_PROFILER_PARK_RATE               ( 1/60 )

#define SYSTEM_PROFILER_PROFILE_DEPTH           ( 40 )
#define SYSTEM_PROFILER_PROFILE_DEPTH_ERR       ( 1.0 )
#define SYSTEM_PROFILER_PROFILE_RATE            ( 1 )
#define SYSTEM_PROFILER_PROFILE_OFF_DEPTH       ( 1.0 )
#define SYSTEM_PROFILER_PROFILE_EXTRA_OOMPH     ( true )


#define SYSTEM_CRUSH_LIMIT_DEPTH                ( 220.0 )

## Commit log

2020-06-02 Adding libraries and schematics.
    Q
    [LCP_Controller.kicad_pcb, LCP_Controller.sch, Microcontroller.sch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]
2020-06-03 Tuesday evening commit, maybe more later
    [LCP_Controller.kicad_pcb, OnboardSensors.sch, Power.sch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]
2020-06-03 Adding USB, and COM1
    [Microcontroller.sch, OnboardSensors.sch, Power.sch]
2020-06-03 Adding more test points and graphics
    [LCP_Controller.kicad_pcb, LCP_Controller.sch, Microcontroller.sch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]
2020-06-04 Split schematic out.
    Split the schematic into much more manageable heirarchical sheets. Should
    be easier to read now
    [ADC_24Bit.sch, Accelerometer.sch, AntennaSwitch.sch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]
2020-06-04 More connections to heirarchical sheets.
    [ADC_24Bit.sch, Accelerometer.sch, AntennaSwitch.sch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]
2020-06-04 Readding more test points.
    My mind is starting to fry. Need to thoroughly review this
    [ADC_24Bit.sch, Accelerometer.sch, AntennaSwitch.sch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]
2020-06-05 Addding battery backup and catching up. now to add regulator
    [ADC_24Bit.sch, Accelerometer.sch, AntennaSwitch.sch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]
2020-06-06 Adding power regulator, and redid labels
    [ADC_24Bit.sch, Accelerometer.sch, AntennaSwitch.sch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]
2020-06-08 Adding battery backup and reset
    [Accelerometer.sch, ArtemisModule.sch, BatteryBackup.sch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]
2020-06-08 Adding comments and labels for Alex to verify
    [ADC_24Bit.sch, Accelerometer.sch, AntennaSwitch.sch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]
2020-06-09 Adding MPNs and more labels to sheets.
    [ADC_24Bit.sch, Accelerometer.sch, AntennaSwitch.sch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]
2020-06-09 Forgot to commit the title block changes
    [ADC_24Bit.sch, Accelerometer.sch, AntennaSwitch.sch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]
2020-09-29 Minor modifications, if any
    [LCP_Controller.kicad_pcb]
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2021-09-10 Unacceptably long time since last commit.
    I've been struggling for weeks with what turned out to be a Artemis hardware issue. These changes reflect a ton of work that is probably best documented in my notebook.
    Things working now:
    * MAX14830 UART & GPIO Write
    * TRS3122E RS232 Control
    * SoundNine OEM Temperature Sensor Read
    * SPI Transfers on Ambiq IOM
    Long way to go, but the foundation is improving
    [LED.c, MAX14830.c, MAX14830.h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]
2021-09-10 Adding the missing files.
    More files that should have been attached to the last commit
    [artemis_iom.c, artemis_max14830.c, artemis_max14830.h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]
2021-09-14 Working version of PA9LD Driver.
    Currently can read pressure and temperature. May be a bug on startup
    where driver doesn't init correctly and goes into a HAL error. Will look
    into this.
    [am_bsp_pins.c, artemis_i2c.c, artemis_pa9ld.c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]
2021-09-29 Adding whoa... Tons to UBLOX.
    This is NOT working, but I need to check it in
    [LED.c, am_bsp_pins.c, depth.c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]
2021-09-29 Adding a new python function to control UBLOX.
    Uses i2cdriver to talk with EVK-M8QEVA-0-00 dev kit. Currently sets I2C and
    reads NAV
2021-09-30 UBlox is 'working' at the moment. Configs for i2c and data reads. Not sure if it is actually working since i can't get a fix in the basement
    [main.c, ublox.c, ublox.h]
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2021-10-20 Adding tons of documentation and fixing crazy amount of errors
    [MAX14830.c, MAX14830.h, artemis_i9603n.c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]
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2023-04-12 K9lx Pressure sensor:
    Implemented K9lx pressure sensor, modified S9 temperature
    sensor files name.
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2023-04-13 main :
    removed the freeRTOS functions for now, Pressure sensor, temperature sensor,
    GPS, and Iridium modem are working
2023-04-19 Kl9x Pressure Sensor :
    formatted the code better, and remove extra whitespaces
2023-04-19 piston control :
    added extra (0x00) byte at the end of command for pistonboard to
    receive proper bytes stream.
    communication between controlboard and pistonboard is working, at least
    piston is being moved fwd and rev
2023-04-19 artemis_piston :
    modified and updated the artemis_piston initialization, added
    extra (0x00) byte to the command to the pistonboard
2023-04-19 am_bsp_pins :
    modified AM_BSP_GPIO_PWR_CTRL_EN pin in the am_bsp_pins.c file,
    which is an control signal to pistonboard
2023-04-19 main :
    formatted the code, added pistonboard interface it's working
    TODO:
    piston gets extended and retracted for now, further commands
    need to be tested
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2023-07-24 artemis_uart : added uart interrupt function to communicate with iridium modem module, and increase the RX/TX buffer size
    NOTE :
    it's functional
2023-07-24 artemis_max14830 : corrected read function
    [artemis_max14830.c]
2023-07-24 am_bsp : increased the RX/TX FIFO level, and uncommented the SPI pins
2023-07-24 S9_temperature : added one second delay after power up, and modified the stop command right after.
2023-07-24 main : added iridium modem i9603n test funcationalities, Real-time clock for gps and time calibration.
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2023-08-12 S9 : modified the receiving end function for proper string parsing, organized and formatted code, S9 temperature sensor-> sequential readings are able to take.
2023-08-24 K9lx: pressure sensor, modified to interrupt based MAX14830, Added reading only pressure function.
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2023-08-25 MAX14830 : modified polling functionalities to interrupt based. reading wait is max 10ms from the device side. Note: freeRTOS write and read functions are not fully functional yet, once freeRTOS is f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
2023-10-02 bsp related : increased uart buffer size, level and baudrate. added SWIO pin for itm printout for IDE debugging. commented necessary conflicts for BSP pins and so.
2023-10-19 ublox gps : fixed the ublox gps files for hanging intermittently
    resons : return length of nav packet throws sometimes negative value
    but receiving variable was unsigned that caused reading
    tremendous length of data from i2c and hung in the loop.
    some functions return values were defined bool but values
    did not return anything.
    cleaned up the code, gps receiving seems to be working fine
    [artemis_i2c.c, ublox.c]
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2023-10-26 piston : added more functions and modified existing functions in artemis_piston and piston files
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2023-10-26 StateMachine and Sensors : added and modified a few changes according to requirements, please see the changes, Work in progress
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2023-11-14 FreeRTOS config : removed ctimer interrupt, increased STACK HEAP and task name size
2023-11-14 Iridium and UART : added un_init uart function for iridium, added FreeRTOS Iridium TASK , being tested for now.
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2023-11-20 StateMachine : working condition statemachin, run through the test pressure profile, and records measurements locally as well as in the SD card through datalogger.
2023-11-20 datalogger : added more functions, test pressure profile load and reset function, replaced pressure with depth recordings
2023-11-20 sensors : added gps timer, and added pressure struct to the reading data
2023-11-20 piston : added more freeRTOS tasks for length, zero, and full piston control
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2023-11-20 piston : fixed the piston getting reset in move_to_full task
    [piston.c]
2023-11-20 piston : fixed the piston reset function, changed to vDelay and added more time testing is required ...
    [piston.c]
2023-11-20 sensors : get the 10 fixs for gps and delete the task
2023-11-20 i9603 : increased the task heap size, fixed the status function argument data type
    [i9603n.c]
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2023-11-21 i9603n : added satellite visible functions, fixed the transmission in the task
    [i9603n.c]
2023-11-21 StateMachine : working with profiles until profile nr. are set in the config.h added TEST functionalities to test the pressure profile faster and test the iridium transmission.
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2024-01-08 datalogger : fixed the I2C error on datalogger writing.
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2024-01-17 StateMachine : modified the move_to_profile for getting out for profile state reseting piston
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2024-05-06 artemis_i2c : printed out i2c error debug, formatted
    [artemis_i2c.c]
2024-05-06 ublox.c : added uninit function for low power, cleaned up the code, fixed nak function's argument data type.
    [ublox.c, ublox.h]
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2024-05-13 sensors : modified the SENS_delete_task, reverted to old way, (wip)
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2024-05-16 StateMachine : added CRITICAL_PISTON_POSITON_DEPTH mechanism which prevents piston to get position after 5.25in length beyond 50m Depth, added rtc time
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2024-06-21 K9lx pressure sensor : correct temperature value in °F
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2025-01-11 Piston Encoder Zero and Crush fix
    Added a new mode to reset the piston encoder counts at full extension to counteract drift. Added functionality to retain state piston position settings after encoder reset. Fixed if hit crush depth reverts to profile mode not pup-up mode.
    [config.h, piston.c]
2025-01-13 Update piston.h
    Add in missing reset to full functions
2025-01-14 Update StateMachine.c
    fix crush depth intelligence, remove timer for faster rise rate below crush depth at 5.25in piston
2025-01-16 Update StateMachine.c
    Correct piston full cal to accurately calculate length change adjustment, now matches zero cal
2025-01-17 Update for correct Cal state length
    Calibration to zero and full reset state length correction now static variables
    [config.h]
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2025-01-22 Update StateMachine.c
    fix issue with double setting piston move flag and increase piston delay frm 1000ms to 2000ms for added momentum time
2025-01-23 piston insitu cal
    fix for longer piston momentum delay
    [piston.c]
2025-01-24 Correct piston reset problems
    add delay for reset functions for piston to move to position
    [piston.c]
2025-01-24 final update for encoder reset
    [config.h]
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2025-01-24 Update piston.c
    more fixes for improved piston comms/ performance
    [piston.c]
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2025-01-30 Fix piston TRV_eng read issue
    Corrects the piston time out issue. Also double the pressure sensor init time to improve performance / eliminate the need to hit the reset button on startup
    [artemis_piston.c]
2025-01-30 Update for new improved when piston in moving
    copy new improved piston reset when piston is already moving to improve function in move to length. Increase delay again for pressure sensor intit
    [piston.c]
2025-02-03 tweaks to avoid memory issues
    [piston.c]
2025-03-05 debug for stack overflow issue
    [piston.c]
2025-03-17 Updates for 03/04/25 testing
    Modify state machine to eliminate issue with piston movement task colliding with following tasks (like GPS), Go back to deleting the piston task in move to length and volume, add delay if piston is already moving in calibration functions.
    [config.h, piston.c]
2025-03-18 Stuck in piston:: length in moving
    Updates to try to solve getting stuck in piston: piston: length in moving loop
    [piston.c]
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2025-03-19 Stall-counter escape
    created stall logic for test_move_piston_to_length function that escapes the loop if the piston isn't moving or if the length value is an invalid float.
    [piston.c]
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2025-03-24 Datalogger off at one point in state machine & changes to piston counter
    Small delays added every time datalogger is turned on. Piston stall counter variables are no longer static.
    [piston.c]
2025-03-24 Revert "Merge pull request #10 from NOAA-PMEL/Datalogger_shutoff"
    This reverts commit 029cc841b4ffa695cc5cda934f86ffd66a530e18, reversing
    changes made to 8c84b7cea09b5af5f6fee8114a3053a885310646.
    [LED.c, MAX14830.c, MAX14830.h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]
